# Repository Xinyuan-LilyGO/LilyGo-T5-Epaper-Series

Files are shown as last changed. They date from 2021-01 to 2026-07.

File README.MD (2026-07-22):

<div align="center" markdown="1">
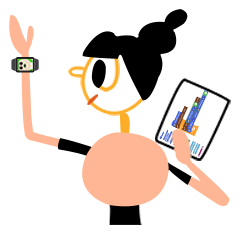
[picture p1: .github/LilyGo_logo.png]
LilyGo logo
  
</div>

<h1 align="center">LilyGo T5 2.13 E-Paper</h1>

### Product

| Product | SOC | Flash | PSRAM |
| --- | ----- | --- | ----- |
| [T5 2.13 Inch][1] | ESP32 | 4MB(Quad-SPI) | N.A |

[1]: https://lilygo.cc/products/t5-v2-3-1

<h2 align="left">Quick Start</h2>

### PlatformIO Quick Start

1. Install the **CH9102 USB bridge** driver for the first time.
   * [Windows](https://www.wch-ic.com/downloads/CH343SER_ZIP.html)
   * [Mac OS](https://www.wch-ic.com/downloads/CH34XSER_MAC_ZIP.html)
2. Install [Visual Studio Code](https://code.visualstudio.com/) and [Python](https://www.python.org/)
3. Search for the `PlatformIO` plugin in the `Visual Studio Code` extension and install it.
4. After the installation is complete, restart `Visual Studio Code`.
5. Select `File` -> `Open Folder` in the upper left corner, then select the `LilyGo-T5-Epaper-Series` directory.
6. Wait for the installation of third-party dependent libraries to complete.
7. Click on the `platformio.ini` file.
8. Uncomment one of the `src_dir = xxxx` lines so that only one is active. For example, to enable `src_dir = examples/Factory`, remove the leading `;` and save the file.
9. Click the (checkmark) symbol in the lower left corner to compile.
10. Connect the board to the computer via Micro-USB.
11. Click (arrow) to upload firmware.
12. Click (plug symbol) to monitor serial output.
13. If the upload fails or the USB device keeps flashing, please check the **FAQ** below.

### Arduino IDE Quick Start

1. Install the **CH9102 USB bridge** driver for the first time.
   * [Windows](https://www.wch-ic.com/downloads/CH343SER_ZIP.html)
   * [Mac OS](https://www.wch-ic.com/downloads/CH34XSER_MAC_ZIP.html)
2. Install [Arduino IDE](https://www.arduino.cc/en/software).
3. Install [Arduino ESP32](https://docs.espressif.com/projects/arduino-esp32/en/latest/).
4. Copy all folders in the `lib` directory to the `Sketchbook location` directory.
   How to find your library path, [see here](https://support.arduino.cc/hc/en-us/articles/4415103213714-Find-sketches-libraries-board-cores-and-other-files-on-your-computer).
   * Windows: `C:\Users\%USERNAME%\Documents\Arduino\libraries`
   * MacOS: `$HOME/Documents/Arduino/libraries`
   * Linux: `$HOME/Arduino/libraries`
5. Open the corresponding example:
   * Open the downloaded `LilyGo-T5-Epaper-Series`
   * Open `examples`
   * Select the sample file ending with `.ino`
6. In Arduino IDE, select the board and settings as shown below:

   | Name                                 | Value                                |
   | ------------------------------------ | ------------------------------------ |
   | Board                                | **ESP32 Dev Module**                 |
   | Port                                 | Your port                            |
   | CPU Frequency                        | 240MHz(WiFi/BT)                      |
   | Core Debug Level                     | None                                 |
   | Erase All Flash Before Sketch Upload | Disable                              |
   | Events Run On                        | Core1                                |
   | Flash Frequency                      | 80MHz                                |
   | Flash Mode                           | QIO                                  |
   | Flash Size                           | **4MB(32Mb)**                        |
   | JTAG Adapter                         | Disabled                             |
   | Arduino Runs On                      | Core1                                |
   | Partition Scheme                     | **Huge APP (3MB No OTA/1MB SPIFFS)** |
   | PSRAM                                | **Disable**                          |
   | Upload Speed                         | 921600                               |
   | Programmer                           | **Esptool**                          |

7. At the top of the sketch, select the screen model you are using: **DEPG0213BN** (default) or **GDEY0213B74**. Uncomment the corresponding line and comment out the other.

### Pins Map

| Name | GPIO NUM |
| --- | --- |
| Display power control | 12 |
| Display MISO | No Connect |
| Display MOSI | 23 |
| Display SCLK | 18 |
| Display DC | 17 |
| Display BUSY | 4 |
| Display RST | 16 |
| Display CS | 5 |
| SD SCK | 14 |
| SD MISO | 2 |
| SD MOSI | 15 |
| SD CS | 13 |
| Battery ADC Pin | 35 |
| Button BOOT | 0 |
| Button 1 | 39 |

* (Display power control) GPIO12 Only V2.4 Version , v2.3.1 version not have this pin

> [!IMPORTANT]
> The ESP32 uses IO2 as the SD card CS pin. You cannot upload software when the SD card is inserted, so remove the SD card before uploading.

### FAQ

- **What is the device's sleep current?**
   1. With the screen power completely off, the external wake-up rate of the ESP32 is approximately 30uA. A complete record of this can be found [here](./examples/DeepSleep/README.MD)

- **Can't upload any sketch? Please enter upload mode manually.**
  1. Connect the board via the USB cable.
  2. Press and hold the BOOT button.
  3. While holding BOOT, press the RST button.
  4. Release the RST button.
  5. Release the BOOT button.
  6. Upload the sketch.

### Resources

- [PCB Dimensions](./dimensions/T5_2.13.dxf)
- [PCB Step](./dimensions/LILYGO_T5%202.13.stp)
- [Schematic](./schematic/T5_2.13.pdf)
- [Cases from users](https://www.printables.com/search/models?ctx=models&q=TTGO+T5)

### Hardware Revision

#### V2.4

* Added GPIO12 control for screen power; improved deep-sleep power consumption (deep-sleep draw is approximately 30µA).
* Added a BOOT button to allow manual entry into download mode if the automatic download circuit fails.
* Optimized WiFi antenna for better WiFi performance.

#### V2.3.1

* Initial version

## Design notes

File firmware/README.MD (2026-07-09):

<div align="center" markdown="1">
  LilyGo logo
</div>

<h1 align = "center">🌟LilyGo-T5 2.13 Inch Firmware</h1>

## Use ESP Download Tool

* [Flash Download Tool User Guide](https://docs.espressif.com/projects/esp-test-tools/en/latest/esp32/production_stage/tools/flash_download_tool.html)

| Steps  | ESP32 Version |
| --- | --- |
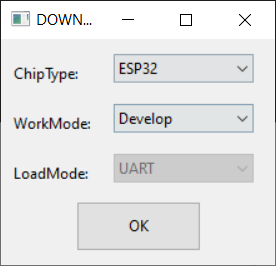
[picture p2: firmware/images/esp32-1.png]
| Step 1 |  |
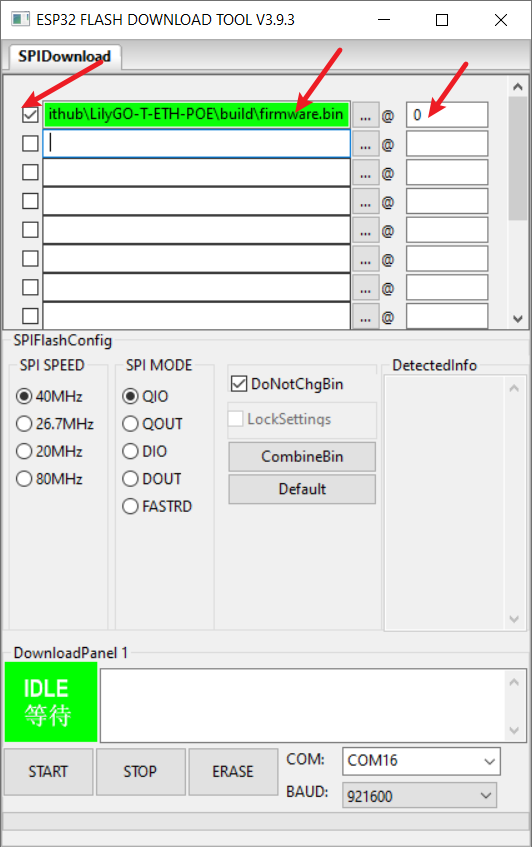
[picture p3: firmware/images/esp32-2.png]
| Step 2 |  |

### Use Web Flasher

* [ESP Web Flasher Online](https://espressif.github.io/esptool-js/)

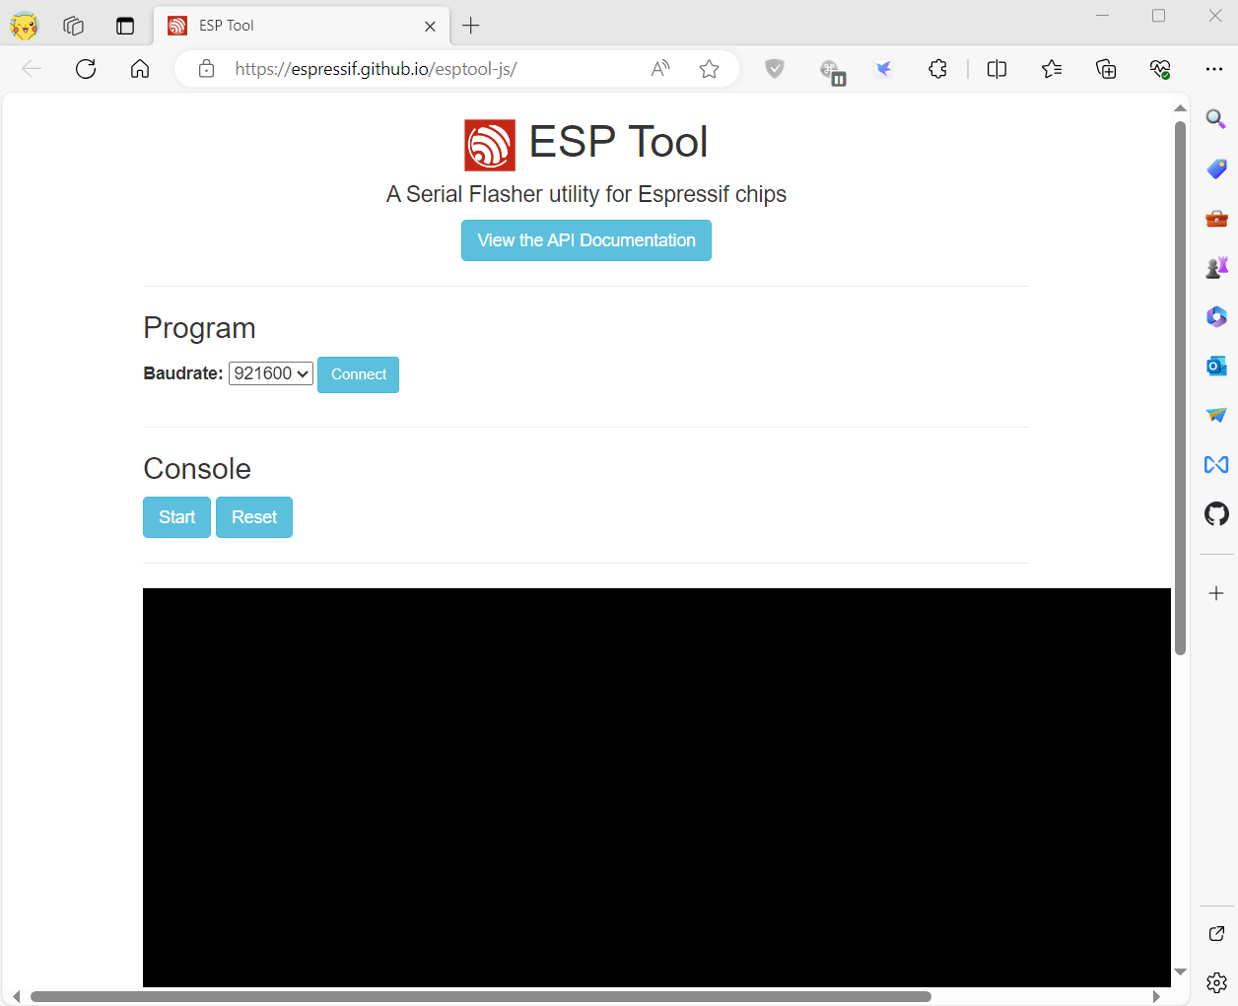
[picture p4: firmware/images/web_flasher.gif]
web_flasher


* Note that after writing is completed, you need to press RST to reset.

### Use command line

If system asks about install Developer Tools, do it.

```bash
python3 -m pip install --upgrade pip
python3 -m pip install esptool
```

In order to launch `esptool.py`, exec directly with this:

```bash
python3 -m esptool
```

<!-- For **ESP32-S3** use the following command to write

```bash
esptool --chip esp32s3  --baud 921600 --before default_reset --after hard_reset write_flash -z --flash_mode dio --flash_freq 80m 0x0 firmware.bin
``` -->

For **ESP32** use the following command to write

```bash
esptool --chip esp32  --baud 921600 --before default_reset --after hard_reset write_flash -z --flash_mode dio --flash_freq 80m 0x0 firmware.bin
```

# 2️⃣FAQ

- **Can't upload any sketch，Please enter the upload mode manually.**
   1. Connect the board via the USB cable
   2. Press and hold the BOOT button , While still pressing the BOOT button 
   3. Press RST button
   4. Release the RST button
   5. Release the BOOT button
   6. Upload sketch

> \[!IMPORTANT]
> ESP32 version Since the SD card uses IO2 as CS, you cannot upload software in the Arduino IDE when you insert the SD card, so you must remove the SD card when uploading new code
>

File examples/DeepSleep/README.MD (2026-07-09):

# Deepsleep Test

[LilyGo T5 V2.4 Deep Sleep Power Consumption Test Record](https://youtube.com/shorts/9wAvt5J69zs)

# GDEY0213B74 Aboud 30 uA

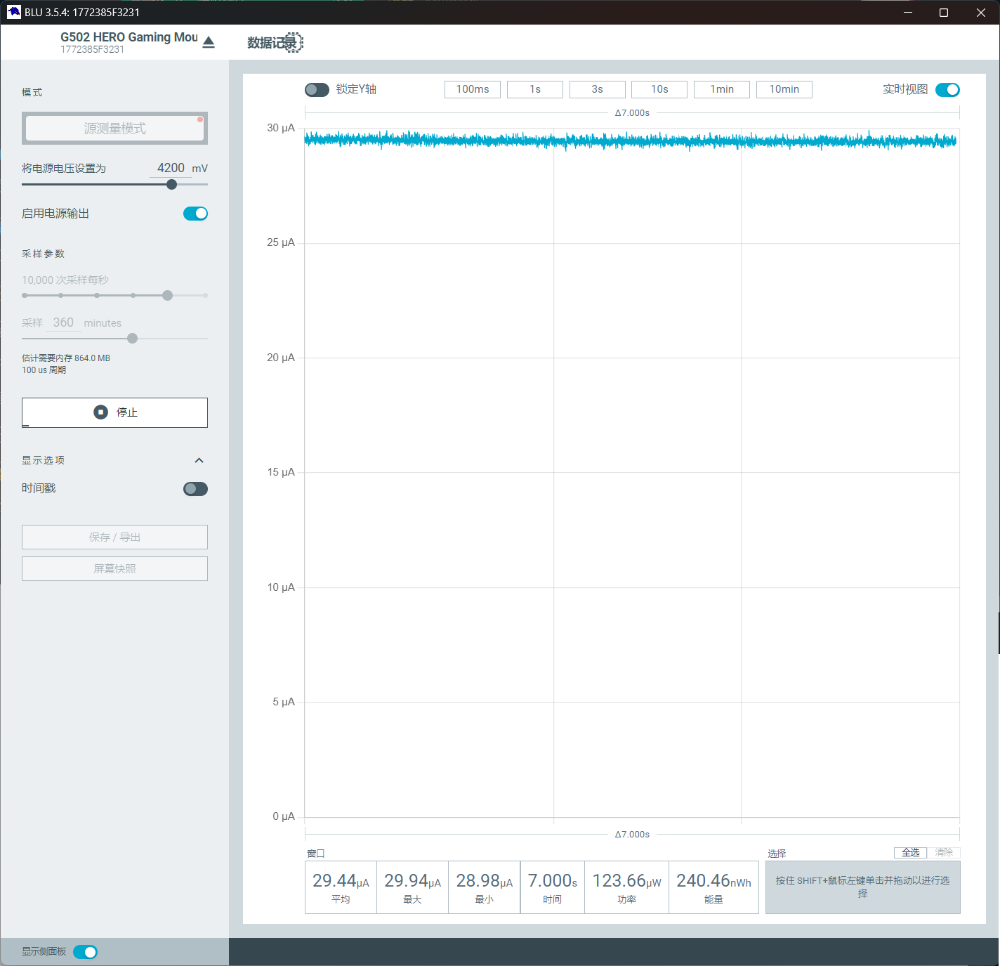
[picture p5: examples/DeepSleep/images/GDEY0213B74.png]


# DEPG0213BN Aboud 30 uA

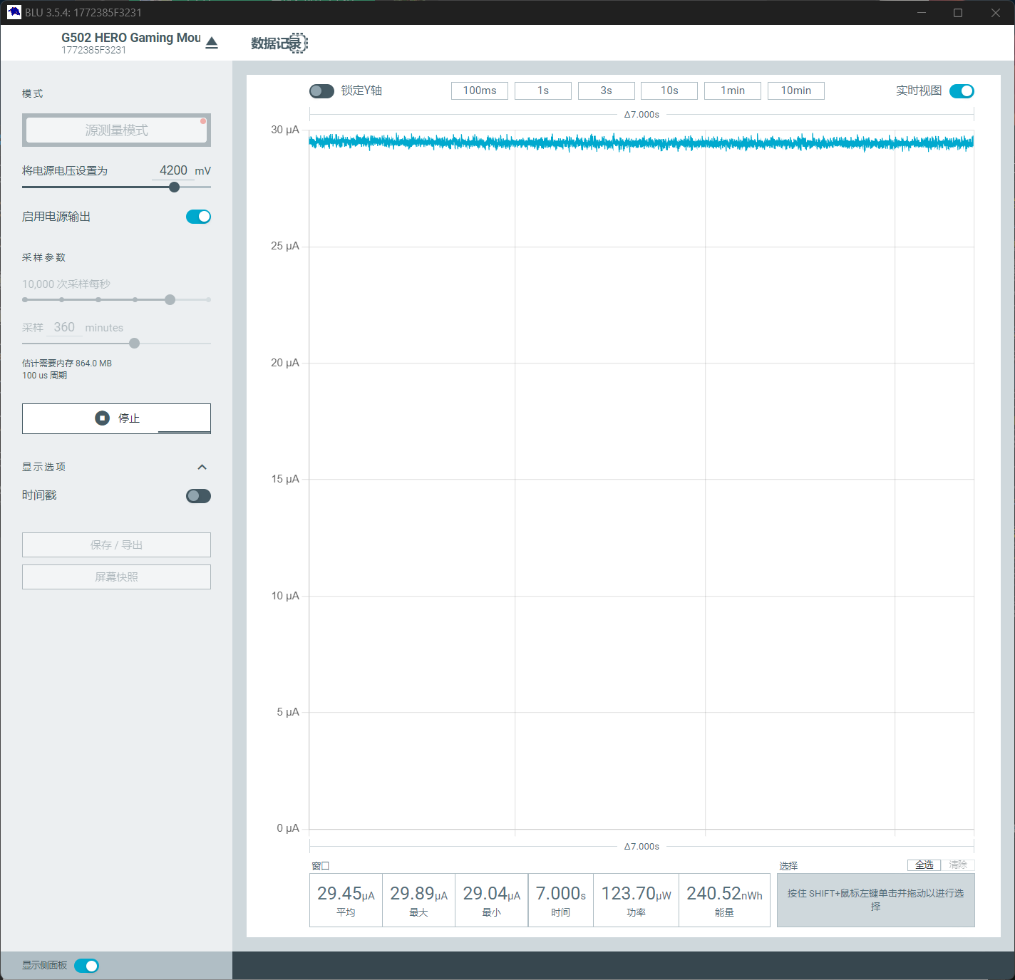
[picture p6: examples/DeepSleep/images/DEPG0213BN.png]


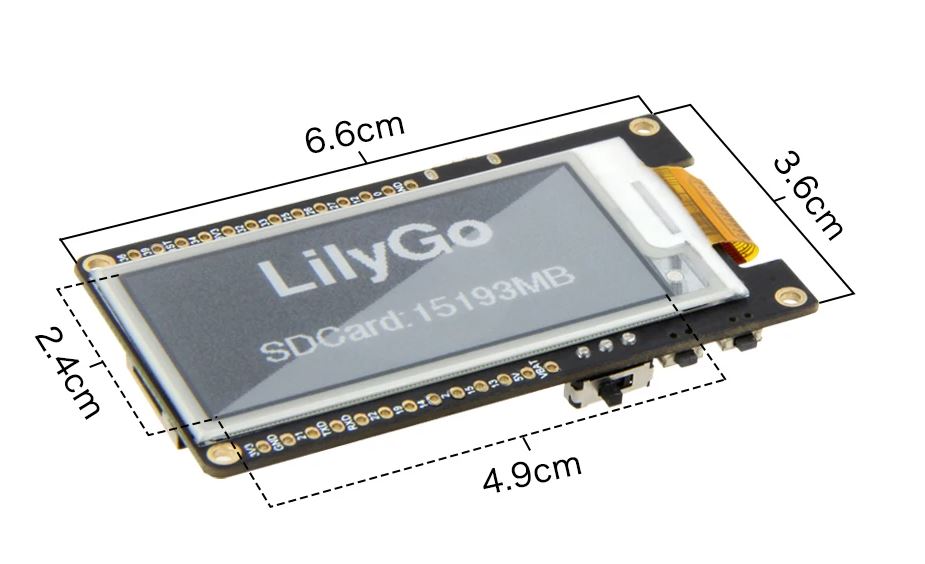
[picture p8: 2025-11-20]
dimensions/Dimensions1.JPG

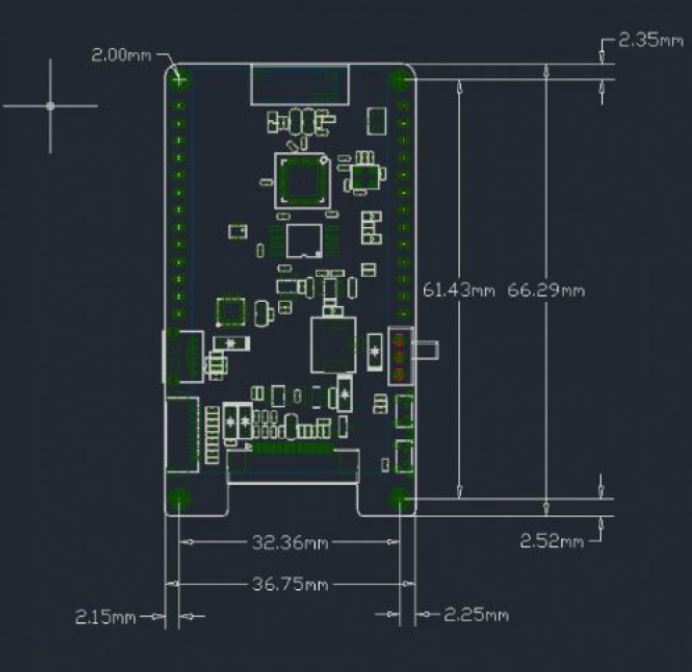
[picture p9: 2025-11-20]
dimensions/Dimensions.JPG

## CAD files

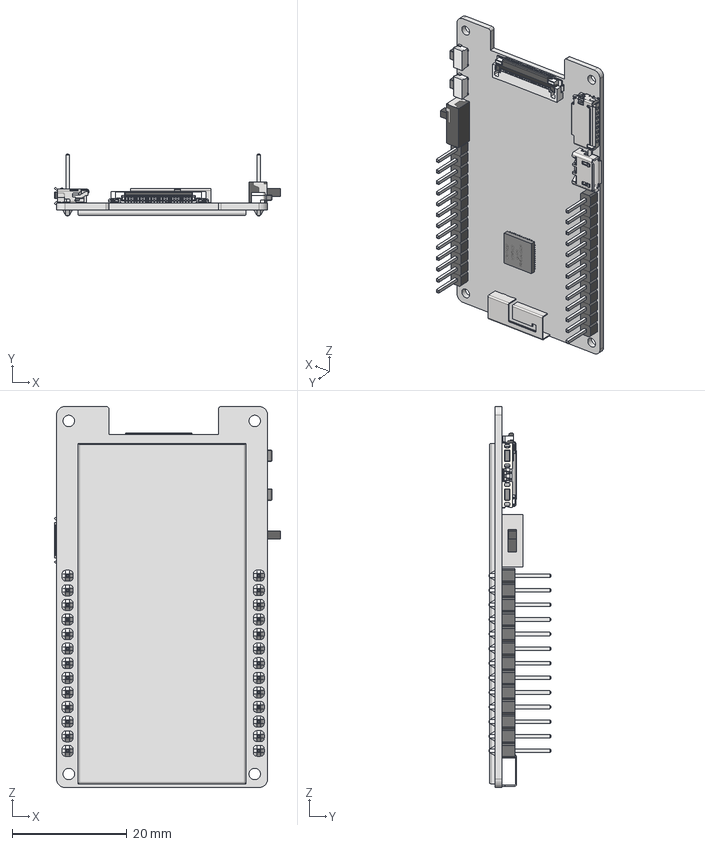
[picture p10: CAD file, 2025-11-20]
dimensions/LILYGO_T5 2.13.stp
39.4 x 10.8 x 66.3 mm
Плата
Antenna, ESP32-PICO-KIT
ESP32-PICO-D4, ESP32-PICO-KIT
Selector Switch
MicroSD Card Connector
Micro USB Shell
FFC Pitch 24
Tact Switch 2x4x3.5MM x 2
Дисплей
2.54 4W Header x 2
2.54 4W Header_ x 10

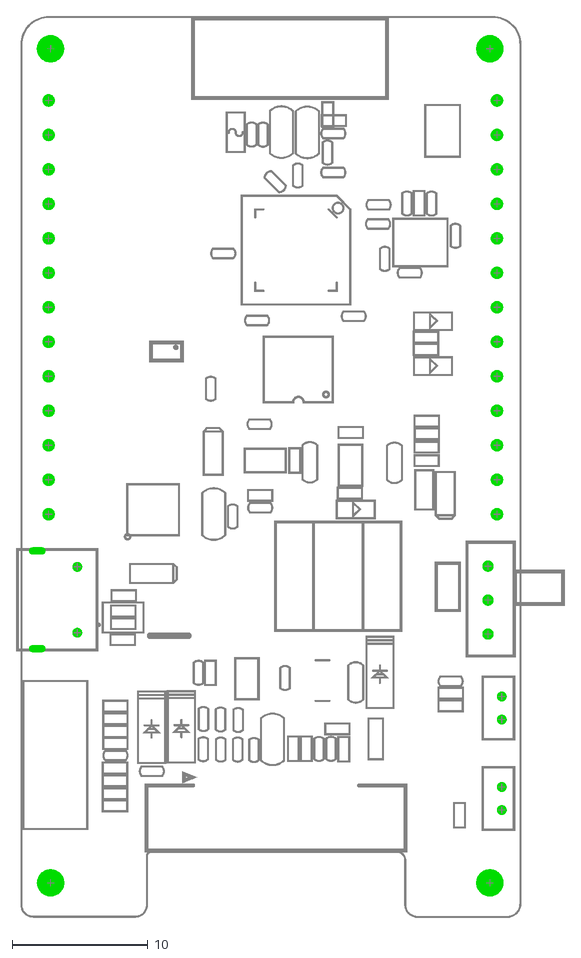
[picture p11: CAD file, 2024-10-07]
dimensions/T5_2.13.dxf
40.4 x 66.4

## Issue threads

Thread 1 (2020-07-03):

Support for GxEPD2?

holgerlembke, 2020-07-03:
Hi.

Is there any support for GxEPD2?

RalfJL, 2021-01-05:
Hi,

for the V2.2 it might be coming up.
See
https://forum.arduino.cc/index.php?topic=487007.msg4845514#msg4845514

lewisxhe, 2021-01-21:
Support, as long as there is a driver in GxEPD2, it can be used. My warehouse is just a demonstration for some novices.

holgerlembke, 2021-01-21:
I appreciate your great product support for some novices.

Closed 2021-01-21.

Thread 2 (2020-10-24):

T5 v2.3 rev. 2.13

ejs-ejs, 2020-10-24:
Hi,
Thank you for the code.
I was playing with GxEPD library and could not get the display.
The T5 version 2.3 rev 2.13 uses GxGDEH0213B73 instead of GxGDEH0213B72. Pins seem to be the same. Maybe the includes could be selected bys #define too?

Also, I've removed #define prom the start of the H file and I can use it as a library:
`#define TTGO_T5_2_3 1
#include <TTGO_T5_boards.h>`

The mentioned code in the H file is as follows:
`#elif (TTGO_T5_2_0) || (TTGO_T5_2_3)
  // #include <GxGDE0213B1/GxGDE0213B1.h>      // 2.13" b/w
  // #include <GxGDE0213B72/GxGDE0213B72.h>      // 2.13" b/w     GxGDE0213B1 升级版本
  //#include <GxGDEH0213B72/GxGDEH0213B72.h> // 2.13" b/w           GxGDE0213B72 升级版本 默认LilyGO的出厂屏幕都是这种
 #include <GxGDEH0213B73/GxGDEH0213B73.h> // 2.13"

  #define SPI_MOSI 23
  #define SPI_MISO -1
  #define SPI_CLK 18

  #define ELINK_SS 5
  #define ELINK_BUSY 4
  #define ELINK_RESET 16
  #define ELINK_DC 17

  #define SDCARD_SS 13
  #define SDCARD_CLK 14
  #define SDCARD_MOSI 15
  #define SDCARD_MISO 2

  #define BUTTON_3 39
  #define BUTTONS_MAP \
    {               \
        39          \
    }

  #define SPEAKER_OUT -1

  #ifdef _GxGDEH0213B72_H_
    #define EPD_WIDTH GxGDEH0213B72_WIDTH
    #define EPD_HEIGHT GxGDEH0213B72_HEIGHT
    #define EPD_VISIBLE_WIDTH GxGDEH0213B72_VISIBLE_WIDTH
  #endif

  #ifdef _GxGDEH0213B73_H_
    #define EPD_WIDTH GxGDEH0213B73_WIDTH
    #define EPD_HEIGHT GxGDEH0213B73_HEIGHT
    #define EPD_VISIBLE_WIDTH GxGDEH0213B73_VISIBLE_WIDTH
  #endif`

ejs-ejs, 2020-10-24:
Sorry, wrong repo...

Closed 2020-10-24.

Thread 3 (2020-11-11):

T5 v2.3 2.13 Board Turn off LED

misaalanshori, 2020-11-11:
I have this board and would like to have it very low power. Is it possible to disable the Blue LED or will I need to just desolder it? It would be great if there is another way to disable it as I don't trust my skill in soldering and I don't know if that led is important (probably not, but I'm not sure).

romoloman, 2020-12-14:
The led should be desoldered, there is no way to disable it (have a lok to the schematics), but for running really low power there are other mods that should be made:
1) A pullup resistor is required between 3.3V and the CS pin on the flash (without that the flash will be always on draining 3 mA
2) The two LDO on board have a quiescent current of about 40uA each, replace them with RT9080 33GJA (2 uA each and the chips are pin to pin compatible)
3) The CP2104 is also draining 200 uA even if not used you need to cut the power supply line to the chip

After these mods I was able to achive less then 30uA in deep sleep mode.

if 318uA is sufficient for you just desolder the led and put a 100K resistor between pin 1 ad 8 of the flash.

I hope Xinyuan makes this mods on the board, maybe making a new version of the board

clonesht, 2021-01-04:
There is a non-hw way to reduce flash memory power usage:

> pinMode(13, OUTPUT);
> digitalWrite(13, HIGH);
> gpio_deep_sleep_hold_en();

[source: reddit](https://old.reddit.com/r/esp32/comments/idinjr/36ma_deep_sleep_in_an_eink_ttgo_t5_v23/ghx00sa/)

@romoloman do you have any stability issues with the RT9080-33GJ5 LDO mod?

According to a [comment](https://web.archive.org/web/20201112030913/https://blog.voneicken.com/2018/lp-wifi-esp32-boards/) it may drop out on peaks:

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

As alternative I have not tried, but [there is some positive experiences](https://www.esp32.com/viewtopic.php?t=6667) on [SOT23-5 version of Holtek HT7833](https://www.holtek.com.tw/documents/10179/82844a36-1633-498c-a6e3-4d99f2d0f6d7) and looks like it have the same pin assignment. (4mA LQC / 500mA out)

lewisxhe, 2021-01-21:
The blue one is the charging indicator, you can remove it without needing to.

Closed 2021-01-21.

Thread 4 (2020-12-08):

Sample code for V2.4

earcam, 2020-12-08:
Hello,

There's currently no sample code for LilyGo T5 V2.4.  Would you please add an example for this board?

Thanks

lewisxhe, 2021-01-21:
In the original address, it has now been updated, V2.4 pin mapping is the same as GxEPD, you can directly use the GxEPD example.

Closed 2021-01-21.

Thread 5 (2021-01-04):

LiPo Voltage Measurement v2.3

Anton2k, 2021-01-04:
Hi, having a hard time trying to figure out how to measure the voltage of the LiPo battery, anyone had success?

Thanks,

Anton2k, 2021-01-04:
Update, I have now found that there is a Pin 35 BAT_TEST, that I can use to measure voltage, the issues is the reading is 2000+ when I was expecting it to me 3.9v I suspect the reading is in MV or something and I need to run it through some calculation?

RalfJL, 2021-01-05:
Have a look at the schematics.
There are 2 100kOhm resistors to prevent the input voltage from being higher than 3.3 V.
So you have to multiply the reading by 2 to get the correct measurement.

By the way, there are plenty of complains on the internet that the ADC is not very good on a ESP32.
Google it and you will find some code to smooth it a little bit.
And don't take the measurement when BLE or WiFi is on. Readings become worse.

Anton2k, 2021-01-07:
Just encase anyone is looking, here us my solution...

`  esp_adc_cal_characteristics_t adc_chars;
  esp_adc_cal_value_t val_type = esp_adc_cal_characterize((adc_unit_t)ADC_UNIT_1, (adc_atten_t)ADC_ATTEN_DB_2_5, (adc_bits_width_t)ADC_WIDTH_BIT_12, 1100, &adc_chars);
  float measurement = (float) analogRead(35);
  float battery_voltage = (measurement / 4095.0) * 7.05;
`

RalfJL, 2021-01-09:
I would recommend the following video
https://www.youtube.com/watch?v=UAJMLTzrM9Q
Normally I am happy with an average of 10 measurements and some correction I found on the internet
So my solution is more that:
double rawVoltage() {
  // read analog and make it more linear
  double reading = analogRead(VOLT_PIN);
  for (int i = 0; i < 10; i++) {
    reading = (analogRead(VOLT_PIN) + reading * 9) / 10;
  }
  if (reading < 1 || reading > 4095) return 0;
  return -0.000000000000016 * pow(reading, 4) + 0.000000000118171 * pow(reading, 3) - 0.000000301211691 * pow(reading, 2) + 0.001109019271794 * reading + 0.034143524634089;
}

All that without wifi or BLE

Closed 2021-01-07.

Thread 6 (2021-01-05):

T5 V2.2 2.9" schematics is wrong

RalfJL, 2021-01-05:
Hi,
the schematics for the above boards seams to be wrong.
The red LED is on with
digitalWrite(26, LOW);
So I assume it has the same connection as all the other boards:
+ -> Resistor -> LED -> PIN26

lewisxhe, 2021-01-21:
The green one is the power indicator, and the red one can be controlled by GPIO26. The green light can be removed if it is not needed.

L-oled, 2022-04-24:
Hi @RalfJL , I was facing to similar issue on the same board when trying to debug with openOCD (issue to find JTAG pinout):
it seem that there is "differents" v2.2 revision of this board.... My board have a JP1 20 pin connectors pinout that corresponds to the one here: http://www.lilygo.cn/prod_view.aspx?TypeId=50061&Id=1397&FId=t3:50061:3
But I didn't manage to find schematics, including on this directory (v2.2 don't match). Except for JP1 pinout, my board looks like a v1.2

Closed 2021-01-21.

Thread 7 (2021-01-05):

T5 V2.2 2.9" green LED can't be turned off

RalfJL, 2021-01-05:
Hi,
according to the schematics the green LED is hardwired and always on.

This is not very good, if you want to run the board on a battery.
There is a battery connector so I assume it was intended for low power consumption.
There should be a better way to disable the green LED, than cutting the resistor off the board.

Regards

lewisxhe, 2021-01-21:
It is a power indicator and cannot be controlled by software, if you don't need to remove it.

Closed 2021-01-21.

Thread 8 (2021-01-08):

Under voltage & Overcharge Protection

Anton2k, 2021-01-08:
Hi, does the T5 v2.3 have built in cut off protection when using Lipo / Ion cells? and does it also have over charge protection? If so can you let me know what values these are, both cut off and over charge. I don't want to blow cells up or discharge them to the point they die.

Thanks,

Anton2k, 2021-01-10:
?

lewisxhe, 2021-01-21:
LILYGO T5 2.3 uses the TP4056 charging chip, which has charging protection, but it does not have reverse connection protection. When you use it, be careful not to mistake the power polarity.

Anton2k, 2021-01-21:
@lewisxhe thanks, but does it have cut off protecting, I need to know at what voltage does discharging stop at, 2.5v 3v?

Anton2k, 2021-01-29:
@lewisxhe ?

lewisxhe, 2021-01-29:
Battery over-discharge protection voltage: 2.5V  @Anton2k

haldi4803, 2021-02-08:
So you guys can confirm that battery works for you?
Because on my T5 v2.2 20181116 does not work when powering via Batteryconnector. I've plugged a battery, i've connected a 4v PSU but the T5 wouldn't even boot up :( No Green light, no Programm start. Do i have faulty hardware?

Closed 2021-01-21.

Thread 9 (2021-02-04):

T5 V2.2 Partial Update Example not working

haldi4803, 2021-02-04:
Hi,
I got the TTGO T5 V2.2 with revision 20181116 using #include <GxGDEH029A1/GxGDEH029A1.h>      // 2.9" b/w the GxEPD_Example works fine.
But the GxEPD_Partial_Update_Example with the same settings seems to work only in Serial but doesn't show anything on the Screen. Not even refreshing. Screen is simply dead.

I think this might be an issue with:
`display.updateWindow(0, 0, GxEPD_WIDTH, GxEPD_HEIGHT, false);`

Because when i use Serial.println before it works but afterwards it doesn't...

haldi4803, 2021-02-04:
Oh -.- the     SPI.begin(EPD_SCLK, EPD_MISO, EPD_MOSI); is missing in the Setup!

Closed 2021-02-04.

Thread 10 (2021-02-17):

T5 4.7 Inch Display

RobertSmart, 2021-02-17:
Hi,

Does this support the lilygo T5 4.7 screen?

Where can I find the firmware for this screen?

lewisxhe, 2021-02-22:
It's here  ， https://github.com/Xinyuan-LilyGO/LilyGo-EPD47

Closed 2021-02-22.

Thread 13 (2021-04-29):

T5 V2.2 2.9" consuming too much power

RalfJL, 2021-04-29:
Hi,
I removed the resistor in front of the green led,
 putting display driver to deep sleep,
putting esp32 to deep sleep
but still the board is consuming 9,35 mA.
This is unacceptable if you want to run it on a battery.
So what is left:
- the UART chip is there any way to turn it off
- the SD-card chip can I put that into deep sleep
- the battery charging chip is there any need to put it in power save mode

Is there any way to reduce the power consumption even more?

joysfera, 2021-05-16:
Seems like the CP2104 itself consumes at least 7 mA. I've read that adding a pulldown to its D- helps a lot.

joysfera, 2021-05-16:
It's possible to lower the consumption in sleep by about 2 mA by disabling flash:
```
pinMode(16, OUTPUT);
digitalWrite(16, HIGH);
gpio_deep_sleep_hold_en();
```
Still 8 mA left.

RalfJL, 2021-05-17:
Hi joysfera,
this is a great hack. Unfortunately everything is so tiny that I can't solder a pulldown resistor to anything.
So unless TTGO changes the layout, I can't see how this board can be powered from battery.
This is a real shame because I put quite some effort to move away from TCP/IP and WiFi to ESP NOW which is much more power saving.
All in vain because of the board itself.

So let's hope that TTGO is learning from this.

Thanks for sharing this information

Ralf

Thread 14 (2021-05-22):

Cannot upload sketch to T5 v2.13

arcaartem, 2021-05-22:
Hello,

I've followed the instructions on this repo and got up to the point where the board and the library is installed. Whenever I try to upload the sketch, I'm getting an error `A fatal error occurred: Failed to connect to ESP32: Timed out waiting for packet header`

I'm on Windows. When I connect the device through USB, I see a new COM port in the device manager. If I open serial monitor on Arduino IDE, I can see the board communicates information on 115200 baud. But the default values for the board when uploading is different. Even if I set them the same, the issue is still there. Is there any other step that we need to do in order to upload sketches to the device?

Thanks!

arcaartem, 2021-05-27:
The method in [this issue](https://github.com/Xinyuan-LilyGO/LilyGo-T-Call-SIM800/issues/89) works for this version of the board as well:

* Short IO0 to GND
* Press the reset button
* Upload the sketch

Closed 2021-05-30.

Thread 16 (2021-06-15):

MacBook Intel CPU with MacOS 11.4 (Big Sur) can not upload anything to T5 board

solocatz, 2021-06-15:
For me only affect Lilygo product, my other low cost esp32 clones are fine.

Try to upload GetChipID sample:

esptool.py v3.0-dev
Serial port /dev/cu.usbmodem526F0051341
Connecting........__
Chip is ESP32-D0WDQ6-V3 (revision 3)
Features: WiFi, BT, Dual Core, 240MHz, VRef calibration in efuse, Coding Scheme None
Crystal is 40MHz
MAC: 08:3a:f2:47:3b:2c
Uploading stub...

A fatal error occurred: Failed to write to target RAM (result was 01070000)
A fatal error occurred: Failed to write to target RAM (result was 01070000)

Here is a link of discussion.
[ESPTool does not work on TTGO product](https://github.com/espressif/esptool/issues/280#issuecomment-861084553)

don41382, 2021-06-15:
I have the same issue with my Macbook M1 Air on Big Sur 11.4.

Please fix!

wecodemx, 2021-06-30:
Same issue here on Macbook intel on Big Sur 11.4
Module: LILYGO® TTGO T-Call V1.4 / V1.5 ESP32

don41382, 2021-06-30:
Good news. After updating with new driver CP102 v6.0.1 from Silabs - it's finally working on my M1.

[Silabs Page](https://www.silabs.com/developers/usb-to-uart-bridge-vcp-drivers)

Let me know, if this works for you.

elajf, 2021-07-01:
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

This didn't work for me but I think mine has a different UART chip, a CH1902. Seems that could be the problem.

matteocarnelos, 2021-07-15:
Same problem here

losdevnull, 2021-07-19:
Same problem here.  Any workaround directly on Mac instead of trying to do this in Windows/linux VMs?

Closed 2022-06-01.

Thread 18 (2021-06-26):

Support in EspEasy firmware

jbaream, 2021-06-26:
Hi,

It would be nice to have a plugin to control these nice eink screens from the firmware ESPEasy. Currently only Lolin ePaper screens are supported. I attach the source file of the plugin for these screens. Is it too difficult to code something similar? What do you think? I am not a expert in advanced programming as to do it. Maybe this can be accomplished by modifying the attached source file.

Best regards,

Jose.
[_P096_eInk.ino.zip](https://github.com/Xinyuan-LilyGO/LilyGo-T5-Epaper-Series/files/6719504/_P096_eInk.ino.zip)

lewisxhe, 2022-06-01:
Looks good, I can try it. Thanks for your advice

Closed 2022-06-01.

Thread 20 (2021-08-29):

lewisxhe / GxEPD boards.h is missing definition for T-Display E-Paper

ShotokuTech, 2021-08-29:
In  lewisxhe / GxEPD boards.h, line 213 change:
#elif defined(LILYGO_EPD_DISPLAY)
to:
#elif defined(LILYGO_EPD_DISPLAY_102)
And this resolves the problem.

LilyGO, 2021-09-11:
Please create a new board. h file, copy the following content into it

#pragma once

#if defined(LILYGO_T5_V213)

#define EPD_MOSI                (23)
#define EPD_MISO                (-1)
#define EPD_SCLK                (18)
#define EPD_CS                  (5)

#define EPD_BUSY                (4)
#define EPD_RSET                (16)
#define EPD_DC                  (17)

#define SDCARD_CS               (13)
#define SDCARD_MOSI             (15)
#define SDCARD_MISO             (2)
#define SDCARD_SCLK             (14)

#define BUTTON_1                (39)
#define BUTTONS                 {39}

#define BUTTON_COUNT            (1)

#define LED_PIN                 (19)
#define LED_ON                  (LOW)

#define ADC_PIN                 (35)

#define _HAS_ADC_DETECTED_
#define _HAS_LED_
#define _HAS_SDCARD_

#elif defined(LILYGO_T5_V22)

#define EPD_MOSI                (23)
#define EPD_MISO                (2)
#define EPD_SCLK                (18)
#define EPD_CS                  (5)

#define EPD_BUSY                (4)
#define EPD_RSET                (12)
#define EPD_DC                  (19)

#define SDCARD_CS               (13)

#define BUTTON_1                (37)
#define BUTTON_2                (38)
#define BUTTON_3                (39)

#define BUTTONS                 {37,38,39}
#define BUTTON_COUNT            (3)

#define LED_PIN                 (26)
#define LED_ON                  (HIGH)

#define ADC_PIN                 (35)

#define SPERKER_PIN             (25)

#define LEDC_CHANNEL_0          (0)
#define _HAS_ADC_DETECTED_
#define _HAS_LED_
#define _HAS_SPEAKER_
#define _BUILTIN_DAC_
#define _USE_SHARED_SPI_BUS_
#define _HAS_SDCARD_

#elif defined(LILYGO_T5_V24)

#define EPD_MOSI                (23)
#define EPD_MISO                (-1) //elink no use
#define EPD_SCLK                (18)

#define EPD_BUSY                (4)
#define EPD_RSET                (16)
#define EPD_DC                  (17)
#define EPD_CS                  (5)

#define SDCARD_CS               (13)
#define SDCARD_MOSI             (15)
#define SDCARD_MISO             (2)
#define SDCARD_SCLK             (14)

#define BUTTON_1                (37)
#define BUTTON_2                (38)
#define BUTTON_3                (39)

#define SPK_POWER_EN                (19)

#define BUTTONS                 {37,38,39}
#define BUTTON_COUNT            (3)

#define LED_PIN                 (26)
#define LED_ON                  (LOW)

#define ADC_PIN                 (35)

#define SPERKER_PIN             (25)

#define LEDC_CHANNEL_0          (0)
#define _HAS_ADC_DETECTED_
#define _HAS_LED_
#define _HAS_SPEAKER_
#define _BUILTIN_DAC_
#define _HAS_SDCARD_
#define _HAS_PWR_CTRL_
#elif defined(LILYGO_T5_V28)

#define EPD_MOSI                (23)
#define EPD_MISO                (-1)
#define EPD_SCLK                (18)
#define EPD_CS                  (5)

#define EPD_BUSY                (4)
#define EPD_RSET                (16)
#define EPD_DC                  (17)

#define SDCARD_CS               (13)
#define SDCARD_MOSI             (15)
#define SDCARD_MISO             (2)
#define SDCARD_SCLK             (14)

#define BUTTON_1                (37)
#define BUTTON_2                (38)
#define BUTTON_3                (39)

#define IIS_WS                  (25)
#define IIS_BCK                 (26)
#define IIS_DOUT                (19)

#define ICS43434_WS             (33)
#define ICS43434_BCK            (32)
#define ICS43434_DIN            (27)

#define I2C_SDA                 (21)
#define I2C_SCL                 (22)

#define BUTTONS                 {37,38,39}
#define BUTTON_COUNT            (3)

#define LED_PIN                 (22)
#define LED_ON                  (HIGH)

#define ADC_PIN                 (35)

#define _HAS_ADC_DETECTED_
#define _HAS_LED_
// #define _HAS_SPEAKER_
#define _HAS_SDCARD_

#elif defined(LILYGO_T5_V102)

#define EPD_MOSI                (21)
#define EPD_MISO                (-1)
#define EPD_SCLK                (22)
#define EPD_CS                  (5)

#define EPD_BUSY                (34)
#define EPD_RSET                (4)
#define EPD_DC                  (19)

#define SDCARD_CS               (13)
#define SDCARD_MOSI             (15)
#define SDCARD_MISO             (2)
#define SDCARD_SCLK             (14)

#define BUTTON_1                (36)
#define BUTTON_2                (39)
#define BUTTON_3                 (0u)//BUTTON_3
#define BUTTONS                 {36,39,0}
#define BUTTON_COUNT            (3)

#define POWER_ENABLE			(27)

#define ADC_PIN                 (35)

#define _HAS_ADC_DETECTED_
#define _HAS_SDCARD_

#elif defined(LILYGO_T5_V266)

#define EPD_MOSI                (23)
#define EPD_MISO                (-1)
#define EPD_SCLK                (18)
#define EPD_CS                  (5)

#define EPD_BUSY                (34)
#define EPD_RSET                (4)
#define EPD_DC                  (19)

#define SDCARD_CS               (13)
#define SDCARD_MOSI             (15)
#define SDCARD_MISO             (2)
#define SDCARD_SCLK             (14)

#define BUTTON_1                (39)
#define BUTTONS                 {39}

#define BUTTON_COUNT            (1)

#define LED_PIN                 (12)
#define LED_ON                  (LOW)

#define ADC_PIN                 (35)

#define _HAS_ADC_DETECTED_
#define _HAS_LED_
#define _HAS_SDCARD_

#elif defined(LILYGO_EPD_DISPLAY_102)

#define EPD_MOSI                (21)
#define EPD_MISO                (-1)
#define EPD_SCLK                (22)
#define EPD_CS                  (5)

#define EPD_BUSY                (18)
#define EPD_RSET                (23)
#define EPD_DC                  (19)

#define EPD_POWER_ENABLE        (14)

#define BUTTON_1                (35)
#define BUTTON_COUNT            (1)

#define ADC_PIN                 (35)
#define RGB_STRIP_PIN           (4)
#define RGB_STRIP_COUNT         (1)

#define _HAS_ADC_DETECTED_
#define _HAS_POWER_CONTROL_
#define _HAS_RGB_PIXEL_

#elif defined(LILYGO_EPD_DISPLAY_154)

#define EPD_MOSI                (13)
#define EPD_MISO                (-1)
#define EPD_SCLK                (14)
#define EPD_CS                  (15)

#define EPD_BUSY                (16)
#define EPD_RSET                (17)
#define EPD_DC                  (2)
#define EPD_BACKLIGHT_PIN       (0)

#define EPD_POWER_ENABLE        (5)

#define BUTTON_1                (35)
#define BUTTON_COUNT            (1)

#define ADC_PIN                 (34)
#define MOTOR_PIN               (4)

#define GPS_TX_PIN              (22)
#define GPS_RX_PIN              (21)
#define GPS_1PPS_PIN            (19)
#define GPS_RESET_PIN           (23)
#define GPS_WAKEUP_PIN          (18)

#define _HAS_ADC_DETECTED_
#define _HAS_POWER_CONTROL_
#define _HAS_GPS_

#else
#error "Please select model !!!"
#endif

carl3, 2022-02-09:
The examples inconsistently use LILYGO_EPD_DISPLAY and LILYGO_EPD_DISPLAY_102 . The "T-Display E-Paper 1.02inch" https://www.aliexpress.com/item/1005002536380666.html with a neopixel RGB LED uses LILYGO_EPD_DISPLAY.

Some of the examples use LILYGO_EPD_DISPLAY_102 instead of LILYGO_EPD_DISPLAY (e.g. hello_world) and some use both (incorrectly, as in GxEPD_Example.ino). In the lewisxhe repo the  Apr 14, 2021  update changed LILYGO_EPD_DISPLAY to LILYGO_EPD_DISPLAY_102 in some examples, but was not added to boards.h. You can define both LILYGO_EPD_DISPLAY_102 and LILYGO_EPD_DISPLAY, but some examples will cause problems.

Probably the boards.h should use ` #elif defined(LILYGO_EPD_DISPLAY) || defined(LILYGO_EPD_DISPLAY_102)` but most examples seem to use LILYGO_EPD_DISPLAY.

lewisxhe, 2022-08-08:
If there is still a problem, please reopen the issue

Closed 2022-08-08.

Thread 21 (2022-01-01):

Battery Voltage example

Martenz, 2022-01-01:
I’m trying to understand how to read battery voltage 1s plugged to the onboard connector but can’t find some good documentation or examples specific for this board.. do I need to create a voltage divider .. is it included in the board?

I have a 1.54 bw and a 2.13 bwr models with speaker.

I tried several how to but none of them works..
please help!

Thanks,

Martino

lewisxhe, 2022-06-01:
All boards have resistor dividers, which one do you use?

lewisxhe, 2022-08-08:
If there is still a problem, please reopen the issue

Closed 2022-08-08.

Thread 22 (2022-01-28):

Unable to use I2C

ChristopheLaurent, 2022-01-28:
I got the T5-2.13 and I try to connect a SCD41 CO2 sensor using I2C. This is basically the same thing as in this tutorial: https://github.com/Sensirion/arduino-ble-gadget/blob/master/documents/SCD4x_BLE_Gadget_Tutorial.md .

The classic scan of I2C bus shows that my sensor is there at address 0x67. So far so good. But when the T5-2.13 is sending commands to the sensor, I get error message "Error trying to execute readMeasurement(): Received NACK on transmit of address". I get this error without any code related to SPI or Ink screen. If I plug a regular ESP32 dev kit instead of the the T5-2.13 , then run the same code on the regular ESP32 dev kit, it works very well, without any I2C error.
I did not put any pull up resistor in both cases, because there is already one on the sensor breakout. In both cases I powered the T5-2.13 and the ESP32 dev kit with USB from my computer.

The peak current @ 3.3V for the SCD41 is 205 mA. Is this issue related to the 3V3 LDO on the T5-2.13 that could be too weak ? Looking at the diagram of the T5-2.13 ( https://github.com/re-innovation/TTGO_EPaper/blob/master/TTGO_Datasheets/T5_V2.3.pdf ) I noticed 2 LDOs, one for 3V3 and one for VCC_IO, but I can only see 3V3 on the pinout.
Any suggestion ?

[EDIT 1] I just tried using another (simpler) sensor: INA 219 DC Current monitor. It works well with regular ESP32 dev kit, not with the T5-2.13: It fails calling ina219.begin(). I then tried using 2 other pins for I2C: pin 25 & pin 26. Still the same problem, it works on ESP32 dev kit but fails the same way on the T5-2.13.

Did someone already manage to use I2C on T5-2.13 ? Could you please provide an example of T5-2.13 displaying ambiant temperature from an I2C sensor, or something along these lines ?

[Edit 2] I eventually found the cause of my problem: solder ! Please close this issue...

Closed 2022-02-23.

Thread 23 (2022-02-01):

The T-Display 1.02 E-Paper schematic is missing

carl3, 2022-02-01:
Can you upload the T-Display E-paper 1.02 schematic? (Aliexpress item 1005002536380666) It would be useful to examine power consumption, input voltage limits, and charging based on the board parts. (The product page links to this github repo.) Perhaps this is the EPD display, but the product on this is also not linked in the README.md

carl3, 2022-06-22:
It looks like the schematic added is the T92 with a 2.66 inch display, seems the same as the T5wth 2.66. The schematic for the T-Display E-paper 1.02 schematic is still missing and not linked. Thanks for updating the readme with a link to the T-Display product.

lewisxhe, 2022-08-08:
The schematic has been added, if there is still a problem, please reopen the issue

Closed 2022-08-08.

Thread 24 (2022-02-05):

Compiling error on LilyGo 2.13 ePaper display (DEPG0213BN)

levycarneiro, 2022-02-05:
Hello!

I'm trying to use a LilyGo 2.13 ePaper display. The model is DEPG0213BN.

I followed the steps in the github repository: Xinyuan-LilyGO/LilyGo-T5-Epaper-Series.

1. I installed Adafruit-GFX library, and the GxEPD library from this repository: https://github.com/lewisxhe/GxEPD

2. I copied all the files from https://github.com/lewisxhe/GxEPD/tree/master/src to my libraries folder.

3. I took the example code from the github repository at  Xinyuan-LilyGO/LilyGo-T5-Epaper-Series/blob/master/examples/GxEPD_Example/GxEPD_Example.ino

4. I uncommented the following lines:

```
#define LILYGO_T5_V213
```

and

```
#include <GxDEPG0213BN/GxDEPG0213BN.h>    // 2.13" b/w  form DKE GROUP
```

5. In my Arduino IDE, I have "ESP32 Dev Module" selected as board.

6. When trying to compile, I get the error:

```
In file included from /Users/xxxxx/Arduino/libraries/GxEPD-lewisxhe/GxEPD.h:20:0,
                 from /Users/xxxxx/Arduino/GxEPD_Example/GxEPD_Example.ino:10:
/Users/xxxxx/Arduino/libraries/GxEPD-lewisxhe/GxFont_GFX.h:77:13: error: 'int16_t GxFont_GFX::getUTF8Width(const char*)' cannot be overloaded
     int16_t getUTF8Width(const char *str);
             ^
/Users/xxxxx/Arduino/libraries/GxEPD-lewisxhe/GxFont_GFX.h:45:13: error: with 'int16_t GxFont_GFX::getUTF8Width(const char*)'
     int16_t getUTF8Width(const char *str);
             ^
```

Any idea how to solve this?

Thanks!

levycarneiro, 2022-02-06:
Problem solved!

See details here:
https://forum.arduino.cc/t/compiling-error-on-lilygo-2-13-epaper-display-depg0213bn/955580/4

Closed 2022-02-06.

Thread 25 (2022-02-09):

Duplicate getUTF8Width definition in lewisxhe/GxEPD causes compile errors

carl3, 2022-02-09:
There are compile errors because getUTF8Width() has duplicate definitions in the lewisxhe/GxEPD fork mentioned as a prerequisite. There is a pull request from https://github.com/bot1131357/GxEPD that fixes the bug by commenting out the duplicate definitions.

The issue cannot be reported on the  lewisxhe/GxEPD fork because issues are disabled.

If you get this compile error, then you would need to use the https://github.com/bot1131357/GxEPD version.

reppr, 2022-02-21:
This issue caused me a lot of troubles...

Why are issues disabled in the lewisxhe fork?
I cannot understand why the problem was there since sept 2021 and is still not fixed.
What should people buying this board do with it, if the supplier cannot supply working software for it?
For me it was a frustrating experience...

@LilyGO
Did LilyGo consider sending a free sample board to the main author of arduino ePaper software?

See also  https://forum.arduino.cc/t/compiling-error-on-lilygo-2-13-epaper-display-depg0213bn/955580/5

tkybundle, 2022-02-22:
I downloaded the lib here, so I was able to make 2.66 work.
https://github.com/Xinyuan-LilyGO/E-Paper-watch/tree/main/lib
anyway yeah, that sucks

lewisxhe, 2022-06-01:
I've been away for a while, since the repository is not maintained, the conflict has now been fixed, it's related to the update of the SDK

Closed 2022-06-01.

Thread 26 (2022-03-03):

T5 V2.3.1_2.13: Unknown E-Paper display, cannot find correct driver

vidhill, 2022-03-03:
I have a `LILYGO® TTGO T5 V2.3.1_2.13 Inch E-Paper Screen New Driver Chip`

The drivers for the e Ink display do not work,

I am using this example https://github.com/Xinyuan-LilyGO/LilyGo-T5-Epaper-Series/blob/master/examples/GxEPD_Example/GxEPD_Example.ino

I have the following line un-commented:
```
 #define LILYGO_T5_V213
```

I believe it is a different E-Paper display to the one referenced

The part number appears to be `WF T0213CZ16 LW`

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

I  can compile and upload,
and I can see that it is running via the serial Monitor, but the display does not update, or render anything

The sketch that was on the board did refresh, so I do not appear to have a faulty board

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

vidhill, 2022-03-07:
I have discovered that the e-paper module labeled `WF T0213CZ16 LW` is in fact [Good Display GDEW0213M21](https://www.good-display.com/product/354.html)

I needed to include the correct library which is:
```c
#elif defined(LILYGO_T5_V213)
// #include <GxDEPG0213BN/GxDEPG0213BN.h>    // 2.13" b/w  form DKE GROUP
#include <GxGDEW0213M21/GxGDEW0213M21.h>
#else
```

This driver is not included in the [GxEPD](https://github.com/ZinggJM/GxEPD) library..

I did find the right driver in randomly included in a number of github repo, https://github.com/ltsochev-dev/esp32-weather-station/tree/main/lib/GxEPD/src/GxGDEW0213M21

For anyone in the same situation as I was,
you need to install [GxEPD](https://github.com/ZinggJM/GxEPD) then copy

* `GxEPD/src/GxGDEW0213M21.h`
* `GxEPD/src/GxGDEW0213M21.cpp`
* `GxEPD/src/BitmapExamples.h`

from https://github.com/ltsochev-dev/esp32-weather-station/tree/main/lib/GxEPD/src/GxGDEW0213M21 into `GxEPD` in you Arduino libraries folder

Closed 2022-03-07.

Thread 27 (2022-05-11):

2.66 inch Lilygo T92_v1.0 support

robouden, 2022-05-11:
For the repo, support for the 2.66 inch Lilygo T92_v1.0  seems to be missing. How t add support for that board?

Regards,
Rob Oudendijk

lewisxhe, 2022-06-01:
Just uncomment `#define LILYGO_T5_V266` in the code . it should work fine

Closed 2022-06-01.

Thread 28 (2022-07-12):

Busy Timeout

Ahmedriazku2, 2022-07-12:
We have lillygo T5 board with 7.5 epaper. With a modification[Modified](https://drive.google.com/file/d/1f_AohgxSAYPVPwo2bbNI2PsKe3KxwP5s/view?usp=drivesdk)  of one spi pin 19/2 we successfully ran Waveshare[Original](https://drive.google.com/file/d/1fPD9XUesdmvl4mZLZVy-TptLoHgot-wX/view?usp=drivesdk)  weather program for two months. But since last ten days something happened, the screen went dimmed and on uploading new data sometimes it uploads but sometimes it gets stuck for days on Busy Timeout. I approached arduino forum where ZinggJM says he wont deal with Lillygo. Please do help.

lewisxhe, 2022-07-13:
You mean it's been working fine for two months? Sudden problems ten days ago?

Ahmedriazku2, 2022-07-13:
Now forget about GxEPD2 and busy timeout. Now when i run your own suggested example file the board is not updated. This is the file  i run: https://drive.google.com/open?id=1guJt0ITGjHKHFWHkqln3H-xrKVm_VhB-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
its the same as your example https://github.com/Xinyuan-LilyGO/LilyGo-T5-Epaper-Series/blob/master/examples/GxEPD_Hello_world/hello_world.ino

now the output is this:
setup
setup done
Hello World

nothing is uploaded on the epaper.

Now first fix this please. And please dont ask more questions.

lewisxhe, 2022-07-13:
I'm so sorry, this problem occurred

You can try to update the compiled binary executable to see if it is a hardware or software problem. Link:
https://github.com/Xinyuan-LilyGO/LilyGo-T5-Epaper-Series/blob/master/firmware/T5_V24_BW_GxDEPG0750BN.bin

Please use espressif flash_download_tools to flash.

https://www.espressif.com.cn/en/tools-type/flash-download-tools

For programming settings, please refer to the readme

https://github.com/Xinyuan-LilyGO/LilyGo-T5-Epaper-Series/tree/master/firmware

lewisxhe, 2022-07-15:
If it still cannot be displayed after refreshing the program, it is very likely that the board is damaged. Please send the uploading program to the board, and then manually reset the board to AliExpress customer service. It is convenient for us to deal with you after sales.

lewisxhe, 2022-08-08:
If you have any other issues, please reopen the issue

Closed 2022-08-08.

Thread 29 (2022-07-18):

Problem achieving 300uA deepsleep current on T5 2.13" v2.3.1

mgsb, 2022-07-18:
I am trying to reproduce the stated 300uA deepsleep current for the 2.13" T5 version 2.3.1 with no LEDs and the DEPG0213BN display http://www.lilygo.cn/claprod_view.aspx?TypeId=62&Id=1391&FId=t28:62:28 . I am measuring 760uA using the deepsleep example from the ESP32-C3 T-OI-Plus repo https://github.com/Xinyuan-LilyGO/LilyGo-T-OI-PLUS/blob/main/example/deepsleep/deepsleep.ino . Do you have an example I can try to reproduce your results? ESP-IDF or Arduino/PlatformIO code?

lewisxhe, 2022-07-19:
The following two sleep modes occupy different sleep currents. I remember that the sleep current of ext1 is the lowest.
```
esp_sleep_disable_wakeup_source(ESP_SLEEP_WAKEUP_TIMER);
esp_sleep_enable_ext1_wakeup(GPIO_NUM, ESP_EXT1_WAKEUP_ALL_LOW);
esp_sleep_enable_ext0_wakeup(GPIO_NUM, 0);
```

lewisxhe, 2022-08-08:
If you have any other issues, please reopen the issue

Closed 2022-08-08.

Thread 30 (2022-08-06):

T5 2.9” V2.2 Deep Sleep Issue

cvocvo, 2022-08-06:
I’m using ESPHome with a T5 2.9” v2.2 epaper, and when I enter deep sleep — shortly after entering deep sleep my screen becomes weird — half white / half black display with artifacts. I will try to post a picture.

The refresh will occur in deep sleep but the display itself won’t recover.

Any ideas? Is deep sleep supported on v2.2?

cvocvo, 2022-08-06:
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

lewisxhe, 2022-08-08:
T5_V2.2 supports deep sleep. If the screen is refreshed after deep sleep is set, please check what is the reason for waking up. I don't use ESPHome. I will rule out the reason for the time being. you can refresh

https://github.com/Xinyuan-LilyGO/LilyGo-T5-Epaper-Series/blob/master/examples/GxEPD_Example/GxEPD_Example.ino

Check if you can sleep normally

cvocvo, 2022-08-08:
I think you're spot on -- I played with the refresh settings a little bit and found a post with a similar issue here: https://github.com/esphome/issues/issues/2334

Once I get it dialed in, I'll post some code this week or this weekend.

cvocvo, 2022-08-11:
I think I got it mostly sorted out; battery life still isn't great but that's a known limitation of v2.2 of the 2.9" board.
Here's what I've got for code -- I solved a bunch of problems (screen reloading issue, deep sleep, sleeping the flash, button to reload, etc.) and posted code up here: https://github.com/cvocvo/esphomeprojects/blob/main/epaper29.yaml

Closed 2022-08-11.

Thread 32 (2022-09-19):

Battery charge %

alfwro13, 2022-09-19:
Hi,
I have LILYGO® TTGO T5 V2.3 2.13 Inch E-Paper Screen and I have connected 3.7v 300mAh battery to the onboad battery connector.
I can see that on the board text written next to the battery connector BAT_TEST_35. What is it and can I use that to calculate battery % charge?

lewisxhe, 2022-09-21:
Yes, IO35 can collect battery voltage

alfwro13, 2022-09-26:
and is there a way to calculate the battery % charge ?

lewisxhe, 2022-09-28:
You can refer to this code

https://github.com/lewisxhe/XPowersLib/blob/master/src/XPowersAXP192.tpp#L1441-L1441

BatsIhor, 2022-12-07:
`   float voltage = analogRead(35) / 4096.0 * 7.46;
    uint8_t percentage = 100;
    if (voltage > 1)
    { // Only display if there is a valid reading
        Serial.println("Voltage = " + String(voltage));
        percentage = 2836.9625 * pow(voltage, 4) - 43987.4889 * pow(voltage, 3) + 255233.8134 * pow(voltage, 2) - 656689.7123 * voltage + 632041.7303;
        if (voltage >= 4.20)
            percentage = 100;
        if (voltage <= 3.50)
            percentage = 0;
        Serial.println("Percentage = " + String(percentage));
}`

BatsIhor, 2023-09-05:
@lewisxhe I checked your link but it's not clear how to use XPowerLib and what is the purpose of it. Do you have any documentation on what it is and when to use it? I was not able to find anything on the internet yet.

lewisxhe, 2023-09-06:
No, I'm just giving you a rough calculation of the percentage. Although it's not accurate, it can achieve the desired effect.

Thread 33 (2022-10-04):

SD card reader not working [T5_V2.3.1_213] (20-8-26)

mrWheel, 2022-10-04:
Hi,

I changed this code:
<pre>
String sizeString = "SD:" + String(SD.cardSize() / 1024.0 / 1024.0 / 1024.0) + "G";
</pre>
to:
<pre>
String sizeString = "SD:" + String(SD.cardSize() / 2048.0 / 2048.0 / 2048.0) + "G";
</pre>
and just to be sure added this line of code:
<pre>
Serial.printf("SD: %dG\r\n", SD.cardSize());
</pre>
If I insert a 2GB microSD card  `SD.cardSize()` returns zero.

I checked the defines with the silkscreen on my board and that all looks good/normal.
The SD card works OK on other devices.

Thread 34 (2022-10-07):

Open to reorganize LilyGo-specific library

rrainey, 2022-10-07:
I have encountered several recent issues keeping the LilyGo specific enhancements to the standard GxEPD library synchronized and up-to-date. It's just not very clean to be manually copying the LilyGo "lib" folder into the Arduino libraries tree by hand. I have a proposal: how about pulling boards.h and associated LilyGo-specific subfolders into a fresh library that logically lays atop GxEPD rather than trying to maintain a separate fork? This new library would be constructed as a standard Arduino library, so the extra dependent libraries could be declared as such.

What are your thoughts on this?

mrWheel, 2022-10-07:
YES!

I'm for it!

I totally removed the `boards.h` file and included the definitions for my board in de sketch.

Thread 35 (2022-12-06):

Is there a way to check it charger is connected?

BatsIhor, 2022-12-06:
Hi there,
On other boards I used battery pin to check voltage and in case it's more than 4.3V I assume usb cable is connected.
But is there other way to make sure charger is connected?
My problem is that some cheap cables and chargers deliver less than 4.3V and in that case device goes to sleep while still on charger.

Thank you
Ihor

lewisxhe, 2022-12-10:
Based on the current circuit, it is impossible to accurately determine whether USB is inserted

Closed 2022-12-10.

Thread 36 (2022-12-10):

Boards.h

Rolzzz, 2022-12-10:
All of your examples fail with the following

"Please edit Boards.h with a hardware abstraction for this board"

lewisxhe, 2022-12-10:
The sketch is compatible with multiple boards, each board has different pin definitions, and the model used needs to be defined above the sketch.
https://github.com/Xinyuan-LilyGO/LilyGo-T5-Epaper-Series/blob/4ad1172a7157b26640b1d359717f24ae34e61af7/examples/GxEPD_Example/GxEPD_Example.ino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

Rolzzz, 2022-12-10:
> The sketch is compatible with multiple boards, each board has different pin definitions, and the model used needs to be defined above the sketch.
>
> https://github.com/Xinyuan-LilyGO/LilyGo-T5-Epaper-Series/blob/4ad1172a7157b26640b1d359717f24ae34e61af7/examples/GxEPD_Example/GxEPD_Example.ino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

I got GxEPD_Example.ino compiled and uploaded but my e-paper isn't functioning, I've emailed support to assist before I can try again

parahooners, 2022-12-28:
Hey - Try and roll back your board manager in Arduino - to 2.0.1 this worked for me

parahooners, 2022-12-28:
i also found that the below worked well with my screen even tho all the setups say use another

#include <GxGDEH0213B73/GxGDEH0213B73.h>  // 2.13" b/w  old panel , form GoodDisplay

Rolzzz, 2022-12-28:
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

support got back to me and showed me to load right FW for board and I got screen working again.

For the Boards.h issue, I also got this worked out.

There are multiple B(b)oards.h files, one is upper case and one is lower case.

once I had both files in different areas read by Arduino IDE plus I had to comment out the first 2 lines of this set and uncomment the next lot then it all worked.

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

Closed 2022-12-28.

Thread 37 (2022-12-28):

issue with ESP32 Board Manager - EPAPER - Arduino - Board Manager

parahooners, 2022-12-28:
Hey just a head up that when using IDE - you will need to roll back the board manager to an earlier version - there is a bug which stops the Epaper boards from working on the newer FW in IDE

Closed 2023-01-27.

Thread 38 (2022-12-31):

T5 V2.3 battery connector type?

masterzen, 2022-12-31:
Hi!
It's not really an issue, but I was wondering what kind of JST (if that's one) connector is used to plug a battery to a T5 V2.3?

Thanks,

lewisxhe, 2023-01-03:
MX1.25MM-2P

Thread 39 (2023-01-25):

Step files

Metatron2k2, 2023-01-25:
I just wanted to ask if it is possible to add step files to the repository. Sorry for raising an issue.

lewisxhe, 2023-01-27:
What does a step file mean?

Metatron2k2, 2023-01-27:
Step file is the 3d Model. It can be created from the original board layout and would be super helpful for constructing 3D cases as we don't have to measure every dimension of the components.

27.01.2023 05:39:12 lewis he ***@***.***>:

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

lewisxhe, 2023-01-27:
Which one do you need? As far as I know, not every model has 3D files. I need to find someone to get these files. If I get these files, I will upload them

Metatron2k2, 2023-01-27:
T5 V2.3 would be awesome!

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

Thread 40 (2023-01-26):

Identify LilyGo-T5-Epaper version -> not available on website nor board

maxbrito500, 2023-01-26:
There exists no identification of the version either on the purchase page nor the board.

There is also no straightforward way to identify the screen model.

The problem is that guessing the board and screen is **not** working. Furthermore, this is a 4.7" screen and there is no driver mentioned there for that model. They are all smaller or bigger.

Purchase page is here: https://www.aliexpress.com/item/1005002272417292.html

If someone can help it would be appreciated.

Developers:
Please consider outputting the board version/details through the serial port with the default firmware. This would already save a lot of difficulty to get this information.

Many thanks!

lewisxhe, 2023-01-27:
The board you buy should correspond to this link:
https://github.com/Xinyuan-LilyGO/LilyGo-EPD47

maxbrito500, 2023-01-27:
Oh my. Thank you!

I got confused and assumed this was the repository for all ePaper modules. Topic solved.

Closed 2023-01-27.

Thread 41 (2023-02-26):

[Linux] Module needed to flash T5?

Shohreh, 2023-02-26:
Hello,

I ordered a ["DEPG0213BN 9102 Chip" T5](https://www.aliexpress.com/item/32869729970.html), altough it says "CH9102F" on the actual hardware I got, and it says "CH340" when connected to Linux.

I can reflash the board successfully on Windows using a web-based flasher.

On Linux, after successuflly compiling a project, it fails flashing the board: "Detecting chip type... Unsupported detection protocol, switching and trying again... Detecting chip type... ESP32-S2".

Is a module needed on Linux?

Thank you.

```
-bash-5.1# lsusb
Bus 001 Device 003: ID 058f:6366 Alcor Micro Corp. Multi Flash Reader
Bus 001 Device 001: ID 1d6b:0002 Linux Foundation 2.0 root hub
Bus 002 Device 005: ID 1a86:55d4 QinHeng Electronics USB Single Serial
Bus 002 Device 002: ID 1a86:7523 QinHeng Electronics CH340 serial converter
Bus 002 Device 001: ID 1d6b:0001 Linux Foundation 1.1 root hub

-bash-5.1# ll /dev/ttyU*
crw-rw---- 1 root dialout 188, 0 Feb 26 20:47 /dev/ttyUSB0

-bash-5.1# idf.py flash /dev/ttyUSB0
Executing action: flash
Serial port /dev/ttyUSB0
Connecting.........
Detecting chip type... Unsupported detection protocol, switching and trying again...
Detecting chip type... ESP32-S2
Running ninja in directory /root/esp/esp-idf/AirMeter.IO.Firmware/build
Executing "ninja flash"...
[1/7] Performing build step for 'bootloader'
[1/1] cd /root/esp/esp-idf/AirMeter.IO.Firmware/build/bootloader/esp-idf/esptool_py && /root/.espressif/python_env/idf5.0_py3.9_env/bin/python /root/esp/esp-idf/components/partition_table/check_sizes.py --offset 0x8000 bootloader 0x1000 /root/esp/esp-idf/AirMeter.IO.Firmware/build/bootloader/bootloader.bin
Bootloader binary size 0x57a0 bytes. 0x1860 bytes (22%) free.
[2/5] cd /root/esp/esp-idf/AirMeter.IO.Firmware/build/esp-idf/esptool_py && /root/.espressif/python_env/idf5.0_py3.9_env/bin/python /root/esp/esp-idf/components/partition_table/check_sizes.py --offset 0x8000 partition --type app /root/esp/esp-idf/AirMeter.IO.Firmware/build/partition_table/partition-table.bin /root/esp/esp-idf/AirMeter.IO.Firmware/build/main.bin
main.bin binary size 0xde0f0 bytes. Smallest app partition is 0x100000 bytes. 0x21f10 bytes (13%) free.
[3/5] cd /root/esp/esp-idf/AirMeter.IO.Firmware/build/esp-idf/main && /root/.espressif/python_env/idf5.0_py3.9_env/bin/python /root/esp/esp-idf/components/spiffs/spiffsgen.py 0x1e000 /root/esp/esp-idf/AirMeter.IO.Firmware/device /root/esp/esp-idf/AirMeter.IO.Firmware/build/dev.bin --page-size=256 --obj-name-len=32 --meta-len=4 --use-magic --use-magic-len
[4/5] cd /root/esp/esp-idf/AirMeter.IO.Firmware/build/esp-idf/main && /root/.espressif/python_env/idf5.0_py3.9_env/bin/python /root/esp/esp-idf/components/spiffs/spiffsgen.py 0xc8000 /root/esp/esp-idf/AirMeter.IO.Firmware/webui/distgz /root/esp/esp-idf/AirMeter.IO.Firmware/build/web.bin --page-size=256 --obj-name-len=32 --meta-len=4 --use-magic --use-magic-len
[4/5] cd /root/esp/esp-idf/components/esptool_py && /usr/bin/cmake -D IDF_PATH=/root/esp/esp-idf -D "SERIAL_TOOL=/root/.espressif/python_env/idf5.0_py3.9_env/bin/python;;/root/esp/esp-idf/components/esptool_py/esptool/esptool.py;--chip;esp32" -D "SERIAL_TOOL_ARGS=--before=default_reset;--after=hard_reset;write_flash;@flash_args" -D WORKING_DIRECTORY=/root/esp/esp-idf/AirMeter.IO.Firmware/build -P /root/esp/esp-idf/components/esptool_py/run_serial_tool.cmake
esptool esp32 -p /dev/ttyUSB0 -b 460800 --before=default_reset --after=hard_reset write_flash --flash_mode dio --flash_freq 40m --flash_size 4MB 0x1000 bootloader/bootloader.bin 0x10000 main.bin 0x8000 partition_table/partition-table.bin 0xd000 ota_data_initial.bin 0x22e000 web.bin 0x2f6000 dev.bin
esptool.py v4.5
Serial port /dev/ttyUSB0
Connecting..........

A fatal error occurred: This chip is ESP32-S2 not ESP32. Wrong --chip argument?
CMake Error at run_serial_tool.cmake:55 (message):

  /root/.espressif/python_env/idf5.0_py3.9_env/bin/python;;/root/esp/esp-idf/components/esptool_py/esptool/esptool.py;--chip;esp32
  failed

FAILED: CMakeFiles/flash
cd /root/esp/esp-idf/components/esptool_py && /usr/bin/cmake -D IDF_PATH=/root/esp/esp-idf -D "SERIAL_TOOL=/root/.espressif/python_env/idf5.0_py3.9_env/bin/python;;/root/esp/esp-idf/components/esptool_py/esptool/esptool.py;--chip;esp32" -D "SERIAL_TOOL_ARGS=--before=default_reset;--after=hard_reset;write_flash;@flash_args" -D WORKING_DIRECTORY=/root/esp/esp-idf/AirMeter.IO.Firmware/build -P /root/esp/esp-idf/components/esptool_py/run_serial_tool.cmake
ninja: build stopped: subcommand failed.
ninja failed with exit code 1, output of the command is in the /root/esp/esp-idf/AirMeter.IO.Firmware/build/log/idf_py_stderr_output_10554 and /root/esp/esp-idf/AirMeter.IO.Firmware/build/log/idf_py_stdout_output_10554
```

lewisxhe, 2023-02-27:
On my Ubuntu, it is not ttyUSB
, but ttyACM0, please check whether the correct port is selected
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

Shohreh, 2023-02-27:
Thanks for the tip. dmesg -wH does show a /dev/ttyACM0 device popping up.

But flashing fails, regardless of the board being ON or OFF:

```
echo "alias get_idf='. $HOME/esp/esp-idf/export.sh'" >> ~/.bashrc
source ~/.bashrc

get_idf

cd ~/esp/esp-idf/AirMeter.IO.Firmware
-bash-5.1# idf.py /dev/ttyACM0 flash
Executing action: /dev/ttyACM0
ninja: error: unknown target '/dev/ttyACM0'
command "/dev/ttyACM0" is not known to idf.py and is not a Ninja target
```

lewisxhe, 2023-02-27:
Are you using idf? You should specify the port like this

```
idf.py -p /dev/tty.ttyACM0 -b 115200 flash

```

Shohreh, 2023-02-27:
Flashing does seem to work with the command I used.

lewisxhe, 2023-02-27:
If the problem is solved, the problem will be closed

Closed 2023-02-27.

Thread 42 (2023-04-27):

my T5 does not connect with usb port. as in the picture

allisonwilliancandido, 2023-04-27:
I'm trying to connect lilygo but windows 10 doesn't recognize the device.
image attached
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

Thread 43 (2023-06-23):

USB disconnects after a few seconds

ramatomo, 2023-06-23:
T5-4,7 S3 on Windows 10
I tried to load first sketch with arduino ide, OWM_EPD47_epaper_v2.5, no error.
However, the screen remained that of the newly purchased device, I tried to reload the sketch but it gave me some errors, after a few times the screen began to disconnect from the USB after a few seconds. I've tried updating USB drivers, changing cables, but to no avail.

ramatomo, 2023-06-26:
thanks

Closed 2023-06-26.

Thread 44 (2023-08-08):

Unable to communicate with T5 v2.3.2 using T-U2T

StevenCellist, 2023-08-08:
Hi guys, I got my hand on a brand-new TTGO T5 v2.3.2 with 2.13 inch e-ink display (not yet released in lilygo.cc but available through reseller).
As per my reseller, the difference w.r.t. v2.3.1 is the need to use the T-U2T to program the board.
This is confirmed by plugging a USB-A to USB-C cable straight into the board: Windows Device Manager doesn't show any port, while the board is being powered and running the example sketch.

When I plug just the T-U2T into my USB cable, Device Manager shows `USB-SERIAL CH340K (COM10)`, indicating that the adapter is working nicely. However, when I plug it into the board, I get no communication at all. When I reset the board using RST button, nothing. When uploading a sketch and pressing BOOT on the U2T, "no serial data received". When holding BOOT and pressing and releasing RST, "no serial data received". I tried another machine, another cable (which did work on other USB-C boards) - no bit of luck.

How should I go about communicating with and programming this device? What could I try? Is there any documentation for this new version 2.3.2?

Attached are pictures of the board, in case that someone wants to look at it.
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

StevenCellist, 2023-08-09:
@lewisxhe thanks for your reply.  I uninstalled the drivers for the specific COM port through Device manager, rebooted and installed your linked drivers. I should note that the installer also shows "CH34SER.INF" as driver name.
Once I connect the U2T, the CH340K name comes back up. And per [this](https://forum.arduino.cc/t/lilygo-ttgo-ch9102f-chip-windows-drivers/949744/5) post, that should work just fine. But still no response from the T5 v2.3.2 :(
Could there be anything else that I'm doing wrong?

lewisxhe, 2023-08-09:
Do you use Windows?

lewisxhe, 2023-08-10:
try this driver
[CH9102.zip](https://github.com/Xinyuan-LilyGO/LilyGo-T5-Epaper-Series/files/12307856/CH9102.zip)

StevenCellist, 2023-08-10:
Did the following:
- uninstall device and check "remove drivers" from Device Manager
- remove U2T
- reboot
- install the .exe
- reboot
- plug in U2T
- Device Manager at first doesn't recognize, just lists "USB Serial"
- after a couple seconds, it apparently installs the drivers and again: CH340K
:( sorry to make this so complicated.. PC is stubborn!

lewisxhe, 2023-08-10:
If it recognizes 340K, then it is really possible that it is 340K.

You try to insert U2T into the board and connect it to the computer via USBC, then open Serial, and click the RST of the board to see what information is output.

lewisxhe, 2023-08-10:
Can the USB screen be updated by inserting it?

StevenCellist, 2023-08-10:
What exactly do you mean by that?
The device does power up and shows the out-of-the-box example animation of squares in the corners, showing all available characters etc.

lewisxhe, 2023-08-10:
Okay, contact the seller and have them send you a new U2T.

StevenCellist, 2023-08-12:
Yes, the 'old' one was not correct! I got sent a new one - the sticker on the box is marked completely different and it shows up as CH9102, and I can successfully read serial information now!

In case anyone ends up here: my incorrectly working one had the box marked with H494, while the working one is marked with Q320 and CH9102F as well.

@lewisxhe thanks for the debugging and thinking along!!

Closed 2023-08-12.

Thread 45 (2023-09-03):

Which driver should I use? Seems none from Hello World example works

tomasz90, 2023-09-03:
On some drivers display is refreshing, but nothing is really displayed.

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

lewisxhe, 2023-09-03:
https://github.com/Xinyuan-LilyGO/LilyGo-T5-Epaper-Series/blob/master/examples/GxEPD_Example/GxEPD_Example.ino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

Board select T5_V21V in sketch

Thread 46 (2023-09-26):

SD card  not working when using T5_V2.3.1_213]

bruno1950, 2023-09-26:
Hi,
I just bought  a Lilygo T5 V2.3.1.213 version GDEM0213B74 CH9102 and I was able to show on display data from I2C sensors (BME280 and SHT3x) and to get a timestamp from RTC DS3231. Deepsleep also works fine. However, I was not able to use the SD card, neither inserting it directly in the slot nor connected to an external SDcard reader ( MOSI IO15,MISO IO2, SCK IOIO14, CS IO13). The card is correctly mounted  but I keep on gettin an error "opening the file" or ""appending the file". Even using a vey simple sketch just to try if it's possible to write something on the SD card is unsuccesful. Since I think that Lilygo is a good brand I have to assume that it's my fault but I was not able to find my mistake. Could anyone tell me which code I have to use just to write data on SD card in order to use it as a datalogger ? Thx in advance

lewisxhe, 2023-09-27:
Please copy your sketch here

bruno1950, 2023-10-01:
Hi,

sorry for the long delay in answering your request but I was in hospital for a programmed surgery that luckily went fine.

Here you have the sketch that doesn't work for what attains the SD card since on the serial monitor I get the message "opening file failed" and "appending file failed" and no data are saved on the SD

When I use this sketch ( clearly with needed modifications) wth the TFT Lilygo board it works just fine.

Thx for your hekp

Bruno

#include <SD.h>
#include <FS.h>

#include <SPI.h>
#include <Wire.h>

#include <RTClib.h> // for the RTC
RTC_DS3231 rtc;

#include <GxFont_GFX.h>

#include <GxEPD2.h>
#include <GxGDEM0213B74/GxGDEM0213B74.h> // specific gor the Lilygo eink display model I have

#include <Fonts/FreeMonoBold9pt7b.h>

#include <GxIO/GxIO_SPI/GxIO_SPI.h>
#include <GxIO/GxIO.h>

#define SPI_MOSI 23
#define SPI_MISO -1
#define SPI_CLK 18
#define ELINK_SS 5
#define ELINK_BUSY 4
#define ELINK_RESET 16
#define ELINK_DC 17

#define SDCARD_SS 13
#define SDCARD_CLK 14
#define SDCARD_MOSI 15
#define SDCARD_MISO 2

GxIO_Class io(SPI, /*CS=5*/ ELINK_SS, /*DC=*/ ELINK_DC, /*RST=*/ ELINK_RESET);
GxEPD_Class display(io, /*RST=*/ ELINK_RESET, /*BUSY=*/ ELINK_BUSY);

SPIClass sdSPI(VSPI);

bool sdOK = false;

#include <Adafruit_Sensor.h>
#include <Adafruit_BME280.h>

#define SEALEVELPRESSURE_HPA (1013.25)
Adafruit_BME280 bme; // I2C

#include <SHT3x.h>
SHT3x Sensor;

// variables to store data from sensors ( float type because they are value with a decimal part)

float TEMP;
float HUM;
float temp;
float hum;

String timeStamp;

String Data;

// variables to define sleep time; the first multiplies the value to get seconds from microseconds; the second says the sleep time in seconds (900 = 15 minutes)
uint64_t uS_TO_S_FACTOR = 1000000;
uint64_t TIME_TO_SLEEP = 900; //sleep for 15 minutes

String dataMessage;

void print_wakeup_reason(){
esp_sleep_wakeup_cause_t wakeup_reason;

wakeup_reason = esp_sleep_get_wakeup_cause();

switch(wakeup_reason)
{
case ESP_SLEEP_WAKEUP_EXT0 : Serial.println("Wakeup caused by external signal using RTC_IO"); break;
case ESP_SLEEP_WAKEUP_EXT1 : Serial.println("Wakeup caused by external signal using RTC_CNTL"); break;
case ESP_SLEEP_WAKEUP_TIMER : Serial.println("Wakeup caused by timer"); break;
case ESP_SLEEP_WAKEUP_TOUCHPAD : Serial.println("Wakeup caused by touchpad"); break;
case ESP_SLEEP_WAKEUP_ULP : Serial.println("Wakeup caused by ULP program"); break;
default : Serial.printf("Wakeup was not caused by deep sleep: %d\n",wakeup_reason); break;
}
}

// setting a counter for data readings; it will increase every time data from sensors are collected
RTC_DATA_ATTR int sensor_data = 0;

#define sensor_data(temp,hum,TEMP,HUM);

// to get time from RTC
void gettimeStamp() {
DateTime now = rtc.now();

char timeStamp[9];
sprintf(timeStamp, "%02i:%02i:%02i", now.hour(), now.minute(), now.second());

Serial.println(timeStamp);
}

// to print on serial monitor data from sensors
void Read_TempHum()
{
Serial.print("Temp_BME280 = ");
Serial.print(temp);
Serial.println(" C");
Serial.print("Hum_BME280 = ");
Serial.print(hum);
Serial.println(" %");
Serial.print("Temp_SHT3x = ");
Serial.print(TEMP);
Serial.println(" C");
Serial.print("Hum_SHT3X = ");
Serial.print(HUM);
Serial.println(" %");
Serial.print(timeStamp);
}

//to display on Eink display data
void displayReadings(){
DateTime now = rtc.now();
char timeStamp[9];
sprintf(timeStamp, "%02i:%02i:%02i", now.hour(), now.minute(), now.second());
display.setCursor(0,0);
display.setTextColor(GxEPD_BLACK);
display.setCursor(0,20);
display.print("temp_BME = ");
display.print(temp);
display.println(" C");
display.print("temp_SHT = ");
display.print(TEMP);
display.println(" C");
display.print("hum_BME = ");
display.print(hum);
display.println(" %");
display.print("hum_SHT = ");
display.print(HUM);
display.println(" %");
display.setCursor(0,100);
display.print(timeStamp);
display.setCursor(100,100);
display.print("Run n ");
display.println(sensor_data);
display.setCursor(0,115);
display.print("Now sleep for 15 min");

display.update();
}

// to save data on SDcard
void logSDCard() {
DateTime now = rtc.now();
char timeStamp[9];
sprintf(timeStamp, "%02i:%02i:%02i", now.hour(), now.minute(), now.second());
dataMessage = String(timeStamp) + "\r\n";
dataMessage = String(timeStamp) + "," +
String(temp) + "," + String(hum)+ "," + String(TEMP) + "," + String(HUM) +"\r\n";
Serial.print("Save data: ");
Serial.println(dataMessage);
appendFile(SD, "/data.txt", dataMessage.c_str());
}

// Write to the SD card
void writeFile(fs::FS &fs, const char * path, const char * message) {
Serial.printf("Writing file: %s\n", path);
File file = fs.open(path, FILE_WRITE);
if(!file) {
Serial.println("Failed to open file for writing");
return;
}
if(file.print(message)) {
Serial.println("File written");
} else {
Serial.println("Write failed");
}
file.close();
}
// Append data to the SD card
void appendFile(fs::FS &fs, const char * path, const char * message) {
Serial.printf("Appending to file: %s\n", path);
File file = fs.open(path, FILE_APPEND);
if(!file) {
Serial.println("Failed to open file for appending");
return;
}
if(file.print(message)) {
Serial.println("Message appended");
} else {
Serial.println("Append failed");
}
file.close();
}

void setup()
{
Serial.begin(115200);
while(!Serial);
delay(100);

// checking the BME280 connections and initializing the sensor
bool status;
status = bme.begin(0x76);
if (!status) {
Serial.println("Could not find a valid BME280 sensor, check wiring!");
while (1);
}

//initializing SD card
sdSPI.begin(SDCARD_CLK, SDCARD_MISO, SDCARD_MOSI, SDCARD_SS);
if (!SD.begin(SDCARD_SS, sdSPI)) {
sdOK = false;
} else {
sdOK = true;
}

Serial.println("SDcard initialized!!");
delay(500);
File file = SD.open("/data.txt");
if(!file) {
Serial.println("File doens't exist");
Serial.println("Creating file...");
writeFile(SD, "/data.txt", "Time, Temperature, Humidity,TEMP,HUM, \r\n");
}
else {
Serial.println("File already exists");
}
file.close();

//initializing the SHT31 sensor
Sensor.Begin();
Sensor.UpdateData();
TEMP = Sensor.GetTemperature();
HUM = Sensor.GetRelHumidity();

delay(100);

// setup for the RTC
if(! rtc.begin()) {
Serial.println("Couldn't find RTC");
while (1);
}
else {
// following line sets the RTC to the date & time this sketch was compiled
rtc.adjust(DateTime(F(__DATE__), F(__TIME__)));
}

temp = bme.readTemperature();
hum = bme.readHumidity();

SPI.begin(SPI_CLK, SPI_MISO, SPI_MOSI, ELINK_SS);
display.init(); // enable diagnostic output on Serial
display.setRotation(1);
display.fillScreen(GxEPD_WHITE);
display.setTextColor(GxEPD_BLACK);
display.setFont(&FreeMonoBold9pt7b);
display.setCursor(0, 0);
delay(1500);

display.update();

Read_TempHum();
displayReadings();
logSDCard();

// increasing the counter for the next data readings

sensor_data++;

Serial.println("Sensor data logged successfully! Going to sleep");

// ESP32 going to sleep for the amount of time you decided
esp_sleep_enable_timer_wakeup(TIME_TO_SLEEP * uS_TO_S_FACTOR);
delay(5000);
esp_deep_sleep_start();

delay(2000);
esp_deep_sleep_start();
}

void loop()
{}

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

lewisxhe, 2023-10-04:
It seems that there is no problem with the SD part. Has the SD card been formatted in FAT32 format? Is the capacity less than 32G? Have you replaced any other SD tests?

bruno1950, 2023-10-04:
Hi, thx for your prompt feedback.
I tried with two different SDcard-adapters and with two different SD cards, one with 4 Gb and the other with 16 Gb, both formatted FAT32, but I still have the same error "Failed to open file for appending"
If I use codes devised to test SDcard (such as the SD_test.ino) I get the error message "Card Mount Failed" both when I insert the card in the slot of the board and if I use an external SD-card reader connected according to instructions.
At this point  one question and one request.
Question: Have you tried to run my sketch ( or a similar one with data collected from an I2C sensor) with SD card on a Lilygo T5_V2.3.1_213 ? Were you successful ?
Request: Would you be so kind to send me  a working code for using SD card  as a data logger with this board ? I was not able to find any simple example of this use  and I need to save on SDcard data collected from an I2C sensor.
Otherwise this board is of no use for me.
 Thx for your help.

lewisxhe, 2023-10-07:
Use the factory test file to test to see if it is normal @bruno1950
[firmware](https://github.com/Xinyuan-LilyGO/LilyGo-T5-Epaper-Series/tree/master/firmware)

bruno1950, 2023-10-17:
Hi,
I tried to use the file factory test as you suggested but I was not able to get a result even following your example.
For firmware I downloaded the [T5_V24_BW_GxGDEM0213B74.bin] because my board is this type. Then I downloaded from Espressif site the ESP32 FLASH DOWNLOAD TOOL but the available version is different from your example and I am blocked. I'm enclosing the pictutes of what I'm getting.
I've also tried to use your SD_test.ino but I got a lot of errors and it doesn't work.
Since I'm a newbie could you you please send me a code for SD card working for my Lilygo board ? or at least telling me where I can find it ?
I've seen that my issue was raised also last year by another user and seems NOT to have been solved (https://github.com/Xinyuan-LilyGO/LilyGo-T5-Epaper-Series/issues/33)

Thanks in advance for your help. The board would be perfect IF the SD card worked
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

lewisxhe, 2023-10-19:
You have burned the wrong firmware, you should have burned
[T5_V213_BW_GxGDEM0213B74.bin](https://github.com/Xinyuan-LilyGO/LilyGo-T5-Epaper-Series/blob/master/firmware/T5_V213_BW_GxGDEM0213B74.bin)

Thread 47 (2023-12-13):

I cannot clear T5 2.31_2.13 display

zsiroslaci, 2023-12-13:
I made a program which wrote text on it. But the text written on display cannot be removed. New text written by new program over write it so the old text pixels and the one  both displayed. The new text  is removable, but the old one cannot.

What can I do to remove old text?

Br
Laszlo

lewisxhe, 2023-12-15:
Is it as if the font is permanently printed on the screen?

zsiroslaci, 2023-12-15:
<!--
/* Font Definitions */
@font-face
	{font-family:"Cambria Math";
	panose-1:2 4 5 3 5 4 6 3 2 4;}
@font-face
	{font-family:Calibri;
	panose-1:2 15 5 2 2 2 4 3 2 4;}
/* Style Definitions */
p.MsoNormal, li.MsoNormal, div.MsoNormal
	{margin:0cm;
	font-size:11.0pt;
	font-family:"Calibri",sans-serif;}
a:link, span.MsoHyperlink
	{mso-style-priority:99;
	color:blue;
	text-decoration:underline;}
span.DefaultFontHxMailStyle
	{mso-style-name:"Default Font HxMail Style";
	font-family:"Calibri",sans-serif;
	color:windowtext;
	font-weight:normal;
	font-style:normal;
	text-decoration:none none;}
.MsoChpDefault
	{mso-style-type:export-only;}
@page WordSection1
	{size:612.0pt 792.0pt;
	margin:70.85pt 70.85pt 70.85pt 70.85pt;}
div.WordSection1
	{page:WordSection1;}
-->Yes. It is permanently printed on the screen.Whath can I do with it?BrLaszlo Küldte a Windows Posta Feladó: Lewis HeElküldve: 2023. december 15., péntek 3:10Címzett: Xinyuan-LilyGO/LilyGo-T5-Epaper-SeriesMásolatot kap: zsiroslaci; AuthorTárgy: Re: [Xinyuan-LilyGO/LilyGo-T5-Epaper-Series] I cannot clear T5 2.31_2.13 display (Issue #47) Is it as if the font is permanently printed on the screen?—Reply to this email directly, view it on GitHub, or unsubscribe.You are receiving this because you authored the thread.Message ID: ***@***.***>

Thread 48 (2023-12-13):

[DEPG0266BN] spiram: SPI RAM not initialized

iw0der, 2023-12-13:
Hi,
I'm experiencing some errors on the hardware module LILYGO® TTGO T5 2.66-Inch E-Paper. Now I want to report here the first problem encountered!

I try to use/enable the external RAM via Arduino IDE but I only get crashes, at most I get to this:

```
Rebooting...
ets Jul 29 2019 12:21:46

rst:0xc (SW_CPU_RESET),boot:0x13 (SPI_FAST_FLASH_BOOT)
configsip: 0, SPIWP:0xee
clk_drv:0x00,q_drv:0x00,d_drv:0x00,cs0_drv:0x00,hd_drv:0x00,wp_drv:0x00
mode:DIO, clock div:1
load:0x3fff0030,len:1344
load:0x40078000,len:13964
load:0x40080400,len:3600
entry 0x400805f0
E (298) spiram: SPI RAM not initialized

abort() was called at PC 0x401027b7 on core 0

Backtrace: 0x400838cd:0x3ffe3af0 0x4008d1cd:0x3ffe3b10 0x400926cd:0x3ffe3b30 0x401027b7:0x3ffe3bb0 0x401027f7:0x3ffe3bd0 0x401026cb:0x3ffe3bf0 0x400e5623:0x3ffe3c20 0x40082fe1:0x3ffe3c50 0x40079316:0x3ffe3c90 |<-CORRUPTED

ELF file SHA256: ee06d735f4dcf31a
```

I chose the ESP32 Wrover Kit as the compilation template but I also tried other combinations... I chose psram enable but when I run the code it gives an error like the one reported.

Am I forgetting some steps or do I have a problem with recognizing the external RAM?

At boot it seems that it is not detected and the crash reports library functions even before my setup:
```
0x400838cd: panic_abort at /Users/ficeto/Desktop/ESP32/ESP32S2/esp-idf-public/components/esp_system/panic.c line 408
0x4008d1cd: esp_system_abort at /Users/ficeto/Desktop/ESP32/ESP32S2/esp-idf-public/components/esp_system/esp_system.c line 137
0x400926cd: abort at /Users/ficeto/Desktop/ESP32/ESP32S2/esp-idf-public/components/newlib/abort.c line 46
0x401027b7: esp_spiram_get_chip_size at /Users/ficeto/Desktop/ESP32/ESP32S2/esp-idf-public/components/esp_hw_support/port/esp32/spiram.c line 145
0x401027f7: esp_spiram_get_size at /Users/ficeto/Desktop/ESP32/ESP32S2/esp-idf-public/components/esp_hw_support/port/esp32/spiram.c line 241
0x401026cb: esp_himem_init at /Users/ficeto/Desktop/ESP32/ESP32S2/esp-idf-public/components/esp_hw_support/port/esp32/esp_himem.c line 134
0x400e5623: start_cpu0_default at /Users/ficeto/Desktop/ESP32/ESP32S2/esp-idf-public/components/esp_system/startup.c line 201
0x40082fe1: call_start_cpu0 at /Users/ficeto/Desktop/ESP32/ESP32S2/esp-idf-public/components/hal/esp32/include/hal/cpu_ll.h line 39

```

Thanks

73,
Arturo.

iw0der, 2023-12-13:
With board "ESP32 Wrover kit (all version)" and an if that uses psramInit() it doesn't crash, but it still says it can't see the external RAM!

```
ets Jul 29 2019 12:21:46

rst:0x1 (POWERON_RESET),boot:0x13 (SPI_FAST_FLASH_BOOT)
configsip: 0, SPIWP:0xee
clk_drv:0x00,q_drv:0x00,d_drv:0x00,cs0_drv:0x00,hd_drv:0x00,wp_drv:0x00
mode:DIO, clock div:1
load:0x3fff0030,len:1344
load:0x40078000,len:13964
load:0x40080400,len:3600
entry 0x400805f0
[   451][I][esp32-hal-psram.c:96] psramInit(): PSRAM enabled
NET: Connecting to WiFi ....
NET: Connected to AP successfully!
NET: IP=10.11.12.13, RSSI=-72
EPD-Test_2c13b83
UTIL: ESP32 Partition table:

| Type | Sub |  Offset  |   Size   |       Label      |
| ---- | --- | -------- | -------- | ---------------- |
|  01  | 02  | 0x009000 | 0x005000 | nvs              |
|  01  | 00  | 0x00E000 | 0x002000 | otadata          |
|  00  | 10  | 0x010000 | 0x140000 | app0             |
|  00  | 11  | 0x150000 | 0x140000 | app1             |
|  01  | 82  | 0x290000 | 0x160000 | spiffs           |
|  01  | 03  | 0x3F0000 | 0x010000 | coredump         |
| ---- | --- | -------- | -------- | ---------------- |

[  2236][I][util.cpp:186] partitionTable(): max APP size: 1280 kB
[  2238][I][util.cpp:202] psRAM(): ========================================
[  2245][W][util.cpp:217] psRAM(): PSRAM is not enabled on this board
[  2251][I][util.cpp:219] psRAM(): ========================================
[  2257][I][util.cpp:220] psRAM(): Internal RAM  size   : 321880
[  2263][I][util.cpp:221] psRAM(): Internal RAM  free   : 251136
[  2269][I][util.cpp:222] psRAM(): ========================================
[  2276][I][util.cpp:258] initID(): ESP32: chip=1, cores=2, revision=3, radio=WiFi/BT/BLE flash=4MB external

```

lewisxhe, 2023-12-15:
It seems that the PSRAM has failed. Contact the seller to replace it.

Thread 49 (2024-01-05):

Sleep current on T5 2.13" v2.3.1

ldab, 2024-01-05:
Related to https://github.com/Xinyuan-LilyGO/LilyGo-T5-Epaper-Series/issues/29

When using the example [examples/GxEPD_Example/GxEPD_Example.ino](https://github.com/Xinyuan-LilyGO/LilyGo-T5-Epaper-Series/blob/master/examples/GxEPD_Example/GxEPD_Example.ino) the sleep current is 635uA from when measuring from the VBAT pin.

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

How was the 300uA measured?

lewisxhe, 2024-04-10:
Measured on the onboard CP2104 UART
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

claudobahn, 2024-11-14:
@lewisxhe I'm having the same issue as @ldab with the same board (T5 2.13" v2.3.1 w/ DEPG0213BN), the lowest I've been able to achieve w/ sleep current is around 600-700 micro amps.

Is your test running with an unmodified board? What sketch are you using? And are you isolating or resetting any of the GPIO before going to deep sleep? Changing any pull-up/down settings?

I'm wondering if there's current drain because of a pull-up/down resistor, either internal to the ESP32 or on the T5 board.

lewisxhe, 2024-11-15:
I did not make any changes, and the example was also tested using https://github.com/Xinyuan-LilyGO/LilyGo-T5-Epaper-Series/blob/master/examples/GxEPD_Example/GxEPD_Example.ino. The only difference is the current test tool.

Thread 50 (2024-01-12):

incorrect pinout on the pinout sheet

rdekens, 2024-01-12:
couldn't get the 266 EPD to work with the examples  until I went back to  GxEPD rather than GxEPD2.
Traced it back to GxEPD using the boards.h file - and from there to the correct pinouts to the 2.66 " epd -
motably - as per the schematics - which are correct  - the Display is
MOSI  23   : correct
MISO  17 :
CLK 18 : correct
CS 5 : correct
RST :  16  WRONG ->  **4**
BUSY 4  WRONG -> **34**
DC not shown - > 19 -  - PIn 19 should be shown as used by the display and not available without due care

pin 17 Appears to have been unused - would have been good if it had been routed out instead of 19 , or used instead with the display.
see attatched modified diagram
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

the examples need to be adjusted to account for the different pinout also

lewisxhe, 2024-01-16:
Thanks for the feedback, I have given it and will make changes soon

Closed 2024-01-16.

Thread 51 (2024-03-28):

Access I2C on T-Dispay E-paper 1.02"

dominator15, 2024-03-28:
Hi, on the model T-Dispay E-paper 1.02" i do not see any output for i2c such as on TTGO T-Display 1.14 Inch LCD. On LCD version there is pin 21 and 22 for I2C but on e-paper version pinout i do not see any port labelled i2c. Does this board not support I2C?

lewisxhe, 2024-04-10:
I2C is freely mapped to IO on both sides, and SDA and SCL are specified during initialization.
For example
```
Wire.begin(5//sda,6//scl)
```

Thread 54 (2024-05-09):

support of T5 Screen-4.7-S3

mars3142, 2024-05-09:
Device: https://www.lilygo.cc/products/t5-4-7-inch-e-paper-v2-3

Are there any plans to support this board?

asg02fever, 2024-07-01:
hey man  , i got the same board , i had only the factory firmware , and i tried to install new one since then there is no working firmware to turn on the display now i havea useless board , can you tell me if u managed to make it work ?

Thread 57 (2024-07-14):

Battery charging stops

mjdudak, 2024-07-14:
I have a T5s 2.7inch. I have hooked up a 3.7V LiPo battery to it and the bright blue charging light will come on for a few seconds but then both the charging light and the regular blinking light from the board running stop, even though it is still plugged into USB power. When measuring the battery with a multimeter, it only reads about 2.1V, which is the same as the reading I am getting from GPIO35. Even when connected for several hours, the battery charge does not go above 2.1V.

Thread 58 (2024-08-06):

PCB Footprints and 3D files (PCB layout) for c2.3.1/v2.3.2

CraigHutchinson, 2024-08-06:
As per title, would be good to have 3D STL of the PCB or layout file as to to be able design a case

Chr0my1702, 2024-08-31:
did this get anywhere?

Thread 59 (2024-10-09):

T5 2.13 VBAT Pin

syoung22071958, 2024-10-09:
Does anyone have information about this pin ?
Is this pin for power supply to the board ?
And if it is, what is the voltage range ?
I don't understand why it is so hard to find this out.
Thanks.

lewisxhe, 2024-10-09:
GPIO35

darkroom2, 2024-10-09:
VBAT pin is connected direct to a battery + terminal

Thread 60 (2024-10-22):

Better build instructions please

drder66, 2024-10-22:
What is the build environment? Is it Visual Studio or something else?
On linux, that would appear to need the Arduino IDE Extension. But where to copy the libraries to?
Can't get past include path problems - added an include to reach boards.h, but most of the other include files are somewhere else.

drder66, 2024-10-22:
So I figured it's the Arduino IDE (standalone, nothing to do with Visual Studio). That sorted, the instructions work

Closed 2024-10-22.

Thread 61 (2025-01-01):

T5 2.13 burned out?

HenryData, 2025-01-01:
Hi, I was trying to upload the sketch from https://github.com/jasonful/Tides/tree/master when at some point the screen greyed out and the T5 stopped communicating.
I've been trying to flash the binary file back to it but it just goes to sync for awhile before I click stop and it outputs
no log file output ...
I have an adafruit TPL5110 board connected connected to pin 13, gnd, and Vbat. And a LI battery connected to the ground and VDD pins on the TPL5110. The TPL5110 still lights up when I plug in the USB to the board or connect the battery to the TPL5110.
I cant reset the screen or upload any code. I guess I must have burnt out the hardware but I'm not sure how.
Is it possible that having the USB and the battery connected at the same time damaged something?
Thanks
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

lewisxhe, 2025-01-02:
Connecting the battery and USB at the same time will not damage the board.

Are you unable to upload now?

Find IO0, connect it to GND, then power on, and finally write the firmware to try

HenryData, 2025-01-03:
After cleaning off a corner of flux and doing this it seems to be unstuck. Still having trouble uploading the sketch but thats a seperate issue and at least the screens responding. Thanks!

Closed 2025-01-03.

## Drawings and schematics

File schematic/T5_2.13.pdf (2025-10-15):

# USB

UART | LDO

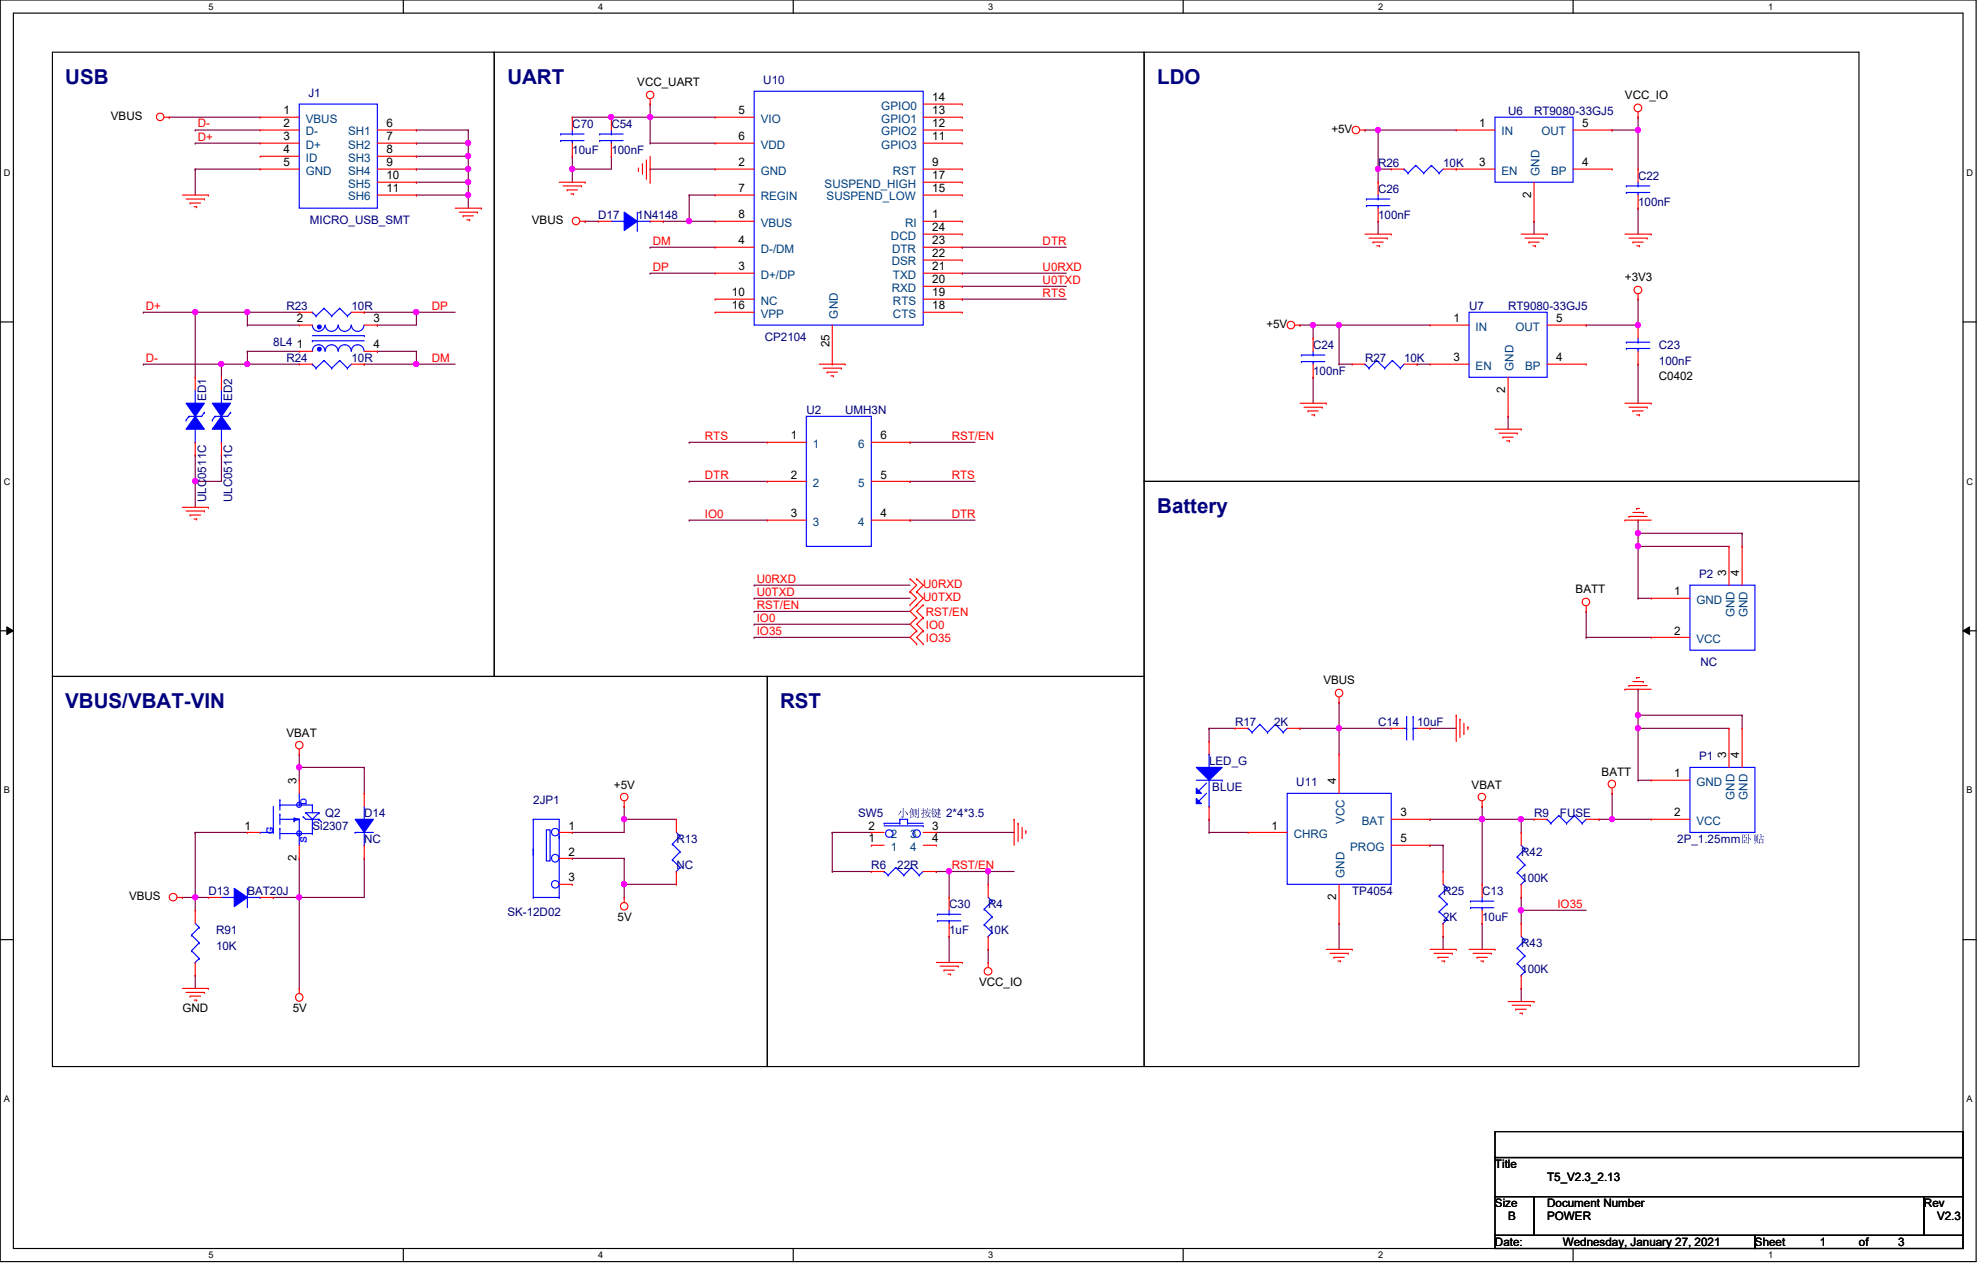
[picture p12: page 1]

# 2.13_Ink screen

## CS-D/IO5

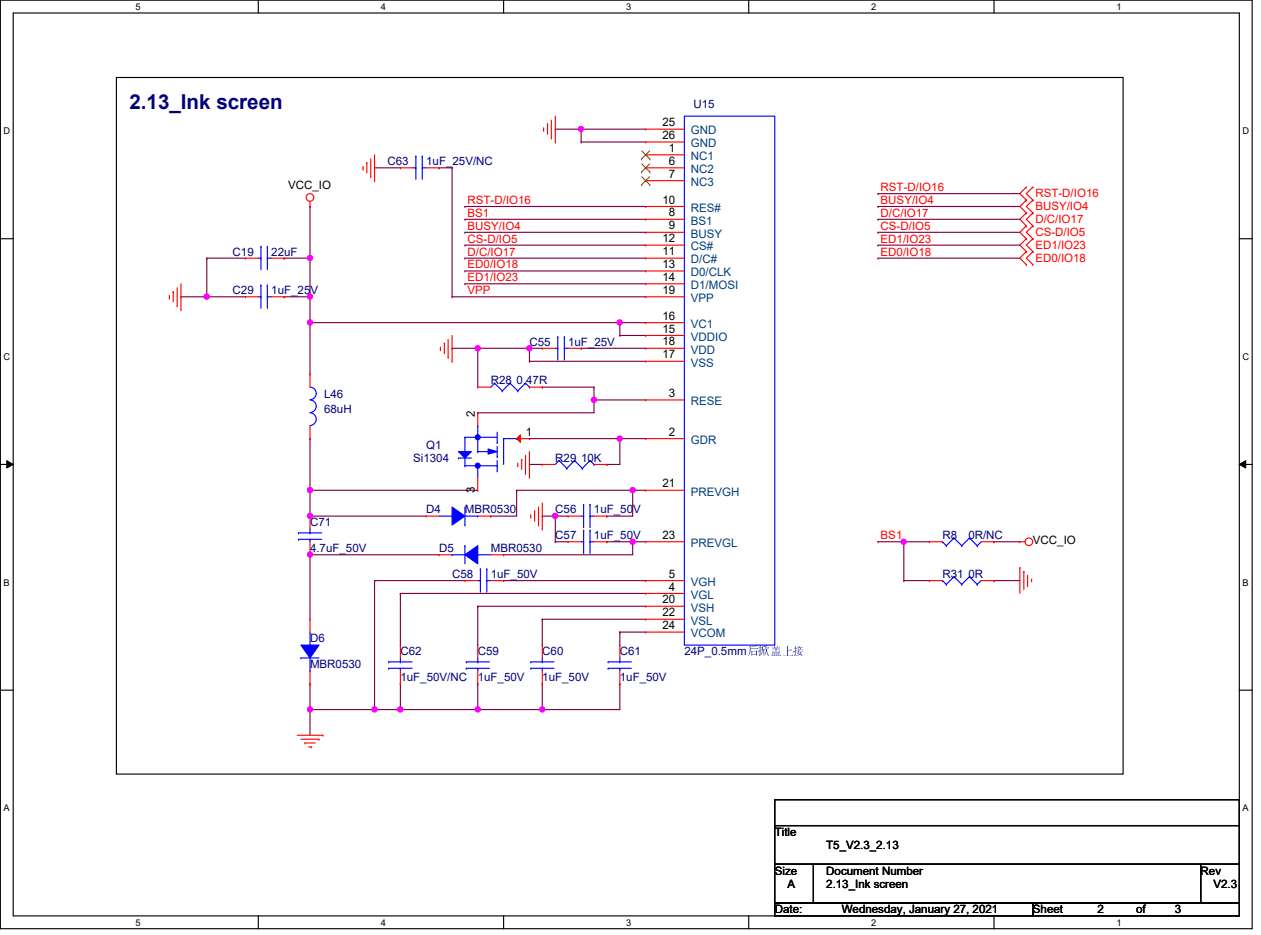
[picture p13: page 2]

Core | GPIO

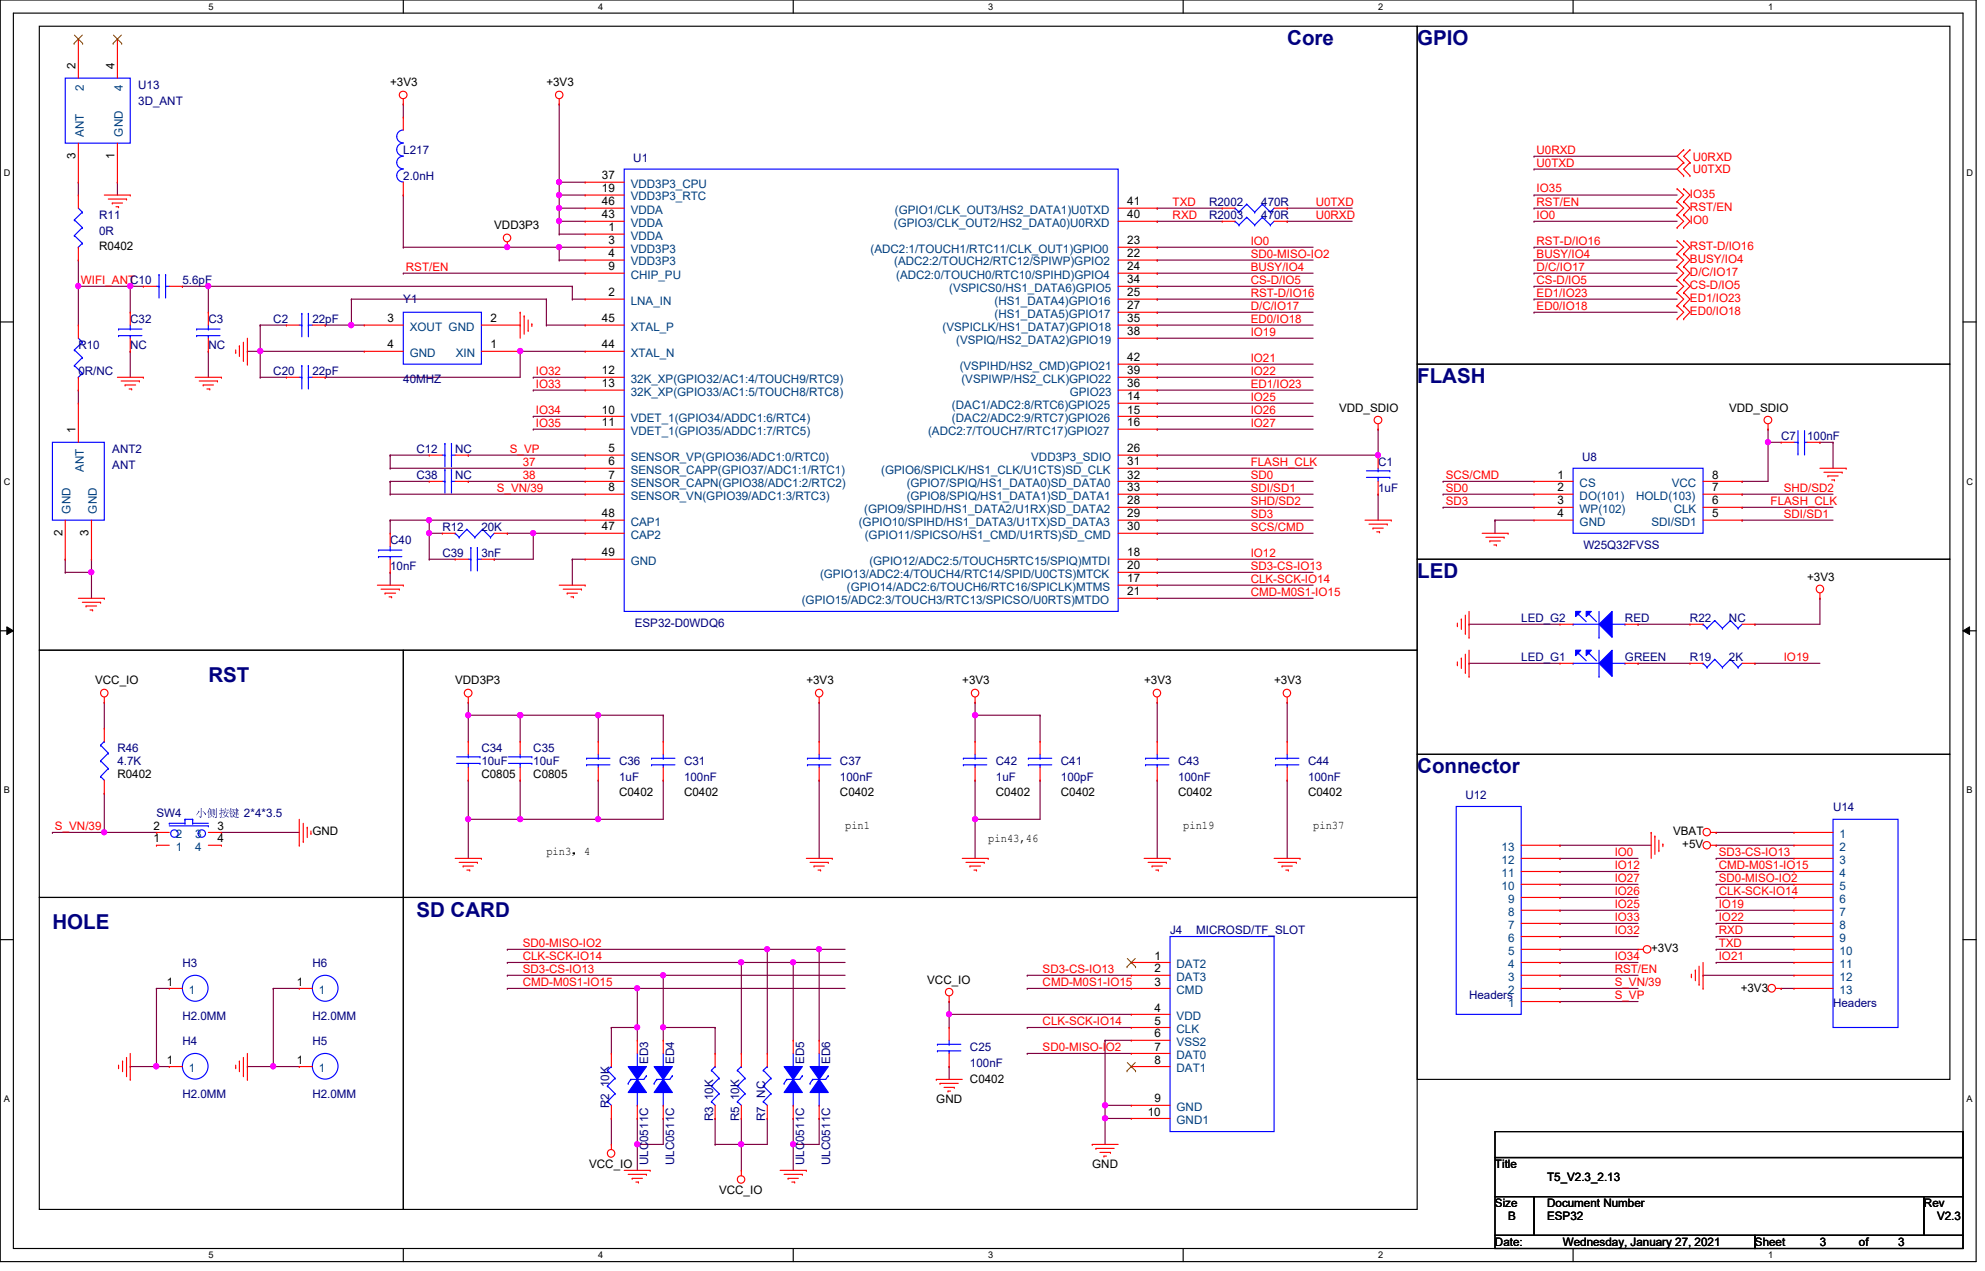
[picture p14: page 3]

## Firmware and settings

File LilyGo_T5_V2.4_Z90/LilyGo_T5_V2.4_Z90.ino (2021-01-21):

#include <SD.h>
#include <SPI.h>
#include <Button2.h>
#include <GxEPD2_3C.h>          //GxEPD2  https://github.com/ZinggJM/GxEPD2
#include <Fonts/FreeMonoBold9pt7b.h>
#include <Fonts/FreeMonoBold12pt7b.h>
#include <Fonts/FreeMonoBold18pt7b.h>
#include <Fonts/FreeMonoBold24pt7b.h>


#define ELINK_BUSY 4
#define ELINK_RESET 16
#define ELINK_DC 17
#define ELINK_SS 5

#define SPI_MOSI 23
#define SPI_MISO -1 //elink no use
#define SPI_CLK 18

#define SDCARD_SS 13
#define SDCARD_MOSI 15
#define SDCARD_MISO 2
#define SDCARD_CLK 14

#define BUTTON_1 37
#define BUTTON_2 38
#define BUTTON_3 39

#define SPEAKER_OUT 25
#define AMP_POWER_CTRL 19
#define CHANNEL_0 0
#define BUTTONS_MAP \
    {               \
        37, 38, 39  \
    }

GxEPD2_3C<GxEPD2_154_Z90c, GxEPD2_154_Z90c::HEIGHT> display(GxEPD2_154_Z90c(
            /*CS*/ ELINK_SS, /*DC*/ ELINK_DC, /*RST*/ ELINK_RESET, /*BUSY*/ ELINK_BUSY)); // GDEH0154Z90


//width:150,height:39
int bmpWidth = 150, bmpHeight = 39;
const unsigned char lilygo[] = {0x00, 0x00, 0x00, 0x00, 0x00, 0x00, 0x00, 0x00, 0x00, 0x00, 0x00, 0x00, 0x00, 0x00, 0x00, 0x00, 0x00, 0x00, 0x00, 0x00, 0x00, 0x00, 0x00, 0x00, 0x00, 0x00, 0x00, 0x00, 0x00, 0x00, 0x00, 0x00, 0x00, 0x00, 0x00, 0x00, 0x00, 0x00, 0x00, 0x00, 0x00, 0x00, 0x00, 0x00, 0x00, 0x00, 0x00, 0x00, 0x00, 0x00, 0x00, 0x00, 0x00, 0x00, 0x00, 0x00, 0x00, 0x00, 0x00, 0x00, 0x00, 0x00, 0x00, 0x00, 0x00, 0x00, 0x00, 0x00, 0x00, 0x00, 0x00, 0x00, 0x00, 0x01, 0xf7, 0x00, 0x00, 0x00, 0x00, 0x00, 0x00, 0x00, 0x00, 0x00, 0x00, 0x00, 0x00, 0x00, 0x00, 0x00, 0x00, 0x00, 0x07, 0x31, 0x80, 0x00, 0x00, 0x00, 0x00, 0x00, 0x00, 0x00, 0x00, 0x00, 0x00, 0x00, 0x00, 0x00, 0x00, 0x00, 0x00, 0x0f, 0xfc, 0xc0, 0x00, 0x00, 0x00, 0x00, 0x00, 0x00, 0x00, 0x00, 0x00, 0x00, 0x00, 0x00, 0x00, 0x00, 0x00, 0x00, 0x0d, 0xfe, 0x60, 0x00, 0x00, 0x00, 0x00, 0x00, 0x00, 0x00, 0x00, 0x00, 0x00, 0x00, 0x00, 0x00, 0x00, 0x00, 0x00, 0x19, 0xff, 0x20, 0x7f, 0xc0, 0x03, 0xfc, 0x7f, 0x80, 0x07, 0xf8, 0x0f, 0xf0, 0x00, 0xfe, 0x00, 0x03, 0xff, 0x80, 0x19, 0xe7, 0x30, 0x7f, 0xc0, 0x03, 0xfc, 0x7f, 0x80, 0x07, 0xfc, 0x0f, 0xf0, 0x07, 0xff, 0xc0, 0x0f, 0xff, 0xe0, 0x19, 0xe7, 0xb0, 0x7f, 0xc0, 0x03, 0xfc, 0x7f, 0x80, 0x03, 0xfc, 0x1f, 0xe0, 0x0f, 0xff, 0xe0, 0x1f, 0xff, 0xf8, 0x19, 0xff, 0x10, 0x7f, 0xc0, 0x03, 0xfc, 0x7f, 0x80, 0x03, 0xfe, 0x1f, 0xe0, 0x1f, 0xff, 0xf0, 0x3f, 0xff, 0xfc, 0x19, 0xff, 0x10, 0x3f, 0xc0, 0x03, 0xfc, 0x7f, 0x80, 0x03, 0xfe, 0x1f, 0xc0, 0x3f, 0xff, 0xf0, 0x7f, 0xff, 0xfe, 0x19, 0xfe, 0x10, 0x3f, 0xc0, 0x03, 0xfc, 0x7f, 0x80, 0x01, 0xfe, 0x3f, 0xc0, 0x7f, 0xff, 0xe0, 0x7f, 0xff, 0xfe, 0x19, 0xfe, 0x10, 0x3f, 0xc0, 0x03, 0xfc, 0x7f, 0x80, 0x01, 0xff, 0x3f, 0x80, 0xff, 0xc7, 0xc0, 0xff, 0xff, 0xff, 0x1d, 0xfe, 0x10, 0x3f, 0xc0, 0x03, 0xfc, 0x7f, 0x80, 0x00, 0xff, 0x7f, 0x80, 0xff, 0x81, 0x80, 0xff, 0xef, 0xff, 0x1d, 0xef, 0x00, 0x3f, 0xc0, 0x03, 0xfc, 0x7f, 0x80, 0x00, 0xff, 0xff, 0x00, 0xff, 0x00, 0x00, 0xff, 0xc3, 0xff, 0x8f, 0xef, 0x00, 0x3f, 0xc0, 0x03, 0xfc, 0x7f, 0x80, 0x00, 0x7f, 0xff, 0x01, 0xff, 0x00, 0x01, 0xff, 0xc3, 0xff, 0x8f, 0x87, 0x80, 0x3f, 0xc0, 0x03, 0xfc, 0x7f, 0x80, 0x00, 0x7f, 0xfe, 0x01, 0xfe, 0x00, 0x01, 0xff, 0xc1, 0xff, 0x87, 0x81, 0xc0, 0x3f, 0xc0, 0x03, 0xfc, 0x7f, 0x80, 0x00, 0x7f, 0xfe, 0x01, 0xfe, 0x1f, 0x81, 0xff, 0x81, 0xff, 0x83, 0xff, 0x80, 0x3f, 0xc0, 0x03, 0xfc, 0x7f, 0x80, 0x00, 0x3f, 0xfc, 0x01, 0xfe, 0x3f, 0xf9, 0xff, 0x81, 0xff, 0x80, 0xfe, 0x00, 0x3f, 0xc0, 0x03, 0xfc, 0x7f, 0x80, 0x00, 0x3f, 0xfc, 0x01, 0xfe, 0x3f, 0xf9, 0xff, 0x81, 0xff, 0x80, 0x00, 0x00, 0x3f, 0xc0, 0x03, 0xfc, 0x7f, 0x80, 0x00, 0x1f, 0xf8, 0x01, 0xfe, 0x3f, 0xf9, 0xff, 0x81, 0xff, 0x80, 0x00, 0x00, 0x3f, 0xc0, 0x03, 0xfc, 0x7f, 0x80, 0x00, 0x1f, 0xf0, 0x01, 0xff, 0x3f, 0xf9, 0xff, 0xc1, 0xff, 0x80, 0x00, 0x00, 0x3f, 0xc0, 0x03, 0xfc, 0x7f, 0x80, 0x00, 0x0f, 0xf0, 0x01, 0xff, 0x3f, 0xf8, 0xff, 0xc1, 0xff, 0x80, 0x00, 0x00, 0x3f, 0xc0, 0x03, 0xfc, 0x7f, 0x80, 0x00, 0x0f, 0xf0, 0x00, 0xff, 0x9f, 0xf8, 0xff, 0xc1, 0xff, 0x80, 0x00, 0x00, 0x3f, 0xc0, 0x03, 0xfc, 0x7f, 0x80, 0x00, 0x0f, 0xf0, 0x00, 0xff, 0x83, 0xf0, 0xff, 0xe1, 0xff, 0x00, 0x00, 0x00, 0x3f, 0xfc, 0x03, 0xfc, 0x7f, 0xf8, 0x00, 0x0f, 0xf0, 0x00, 0xff, 0xe3, 0xf0, 0x7f, 0xff, 0xff, 0x00, 0x00, 0x00, 0x3f, 0xff, 0xe3, 0xfc, 0x7f, 0xff, 0xc0, 0x0f, 0xf0, 0x00, 0x7f, 0xff, 0xf0, 0x7f, 0xff, 0xfe, 0x00, 0x00, 0x00, 0x3f, 0xff, 0xe3, 0xfc, 0x7f, 0xff, 0xc0, 0x0f, 0xf0, 0x00, 0x7f, 0xff, 0xf0, 0x3f, 0xff, 0xfe, 0x00, 0x00, 0x00, 0x3f, 0xff, 0xe3, 0xfc, 0x7f, 0xff, 0xc0, 0x0f, 0xf0, 0x00, 0x3f, 0xff, 0xf0, 0x3f, 0xff, 0xfc, 0x00, 0x00, 0x00, 0x3f, 0xff, 0xe3, 0xfc, 0x7f, 0xff, 0xc0, 0x0f, 0xf0, 0x00, 0x1f, 0xff, 0xf0, 0x1f, 0xff, 0xfc, 0x00, 0x00, 0x00, 0x3f, 0xff, 0xe3, 0xf8, 0x7f, 0xff, 0xc0, 0x0f, 0xf0, 0x00, 0x0f, 0xff, 0xf0, 0x0f, 0xff, 0xf8, 0x00, 0x00, 0x00, 0x1f, 0xff, 0xc3, 0xf8, 0x1f, 0xff, 0xc0, 0x0f, 0xe0, 0x00, 0x03, 0xff, 0xe0, 0x03, 0xff, 0xe0, 0x00, 0x00, 0x00, 0x00, 0x3f, 0xc0, 0xf0, 0x00, 0x3f, 0x80, 0x07, 0xe0, 0x00, 0x00, 0xff, 0x80, 0x01, 0xff, 0xc0, 0x00, 0x00, 0x00, 0x00, 0x00, 0x00, 0x00, 0x00, 0x00, 0x00, 0x00, 0x00, 0x00, 0x00, 0x00, 0x00, 0x00, 0x3e, 0x00, 0x00, 0x00, 0x00, 0x00, 0x00, 0x00, 0x00, 0x00, 0x00, 0x00, 0x00, 0x00, 0x00, 0x00, 0x00, 0x00, 0x00, 0x00, 0x00, 0x00, 0x00, 0x00, 0x00, 0x00, 0x00, 0x00, 0x00, 0x00, 0x00, 0x00, 0x00, 0x00, 0x00, 0x00, 0x00, 0x00, 0x00, 0x00, 0x00, 0x00, 0x00, 0x00, 0x00, 0x00, 0x00, 0x00, 0x00, 0x00, 0x00, 0x00, 0x00, 0x00, 0x00, 0x00, 0x00, 0x00, 0x00, 0x00, 0x00, 0x00};

const char *skuNum = "SKU:H215";
int startX = 30, startY = 50;

Button2 *pBtns = nullptr;
SPIClass SDSPI(VSPI);
uint8_t g_btns[] = BUTTONS_MAP;
bool sdOK = false;


void button_callback(Button2 &b)
{
    for (int i = 0; i < sizeof(g_btns) / sizeof(g_btns[0]); ++i) {
        if (pBtns[i] == b) {
            Serial.printf("Button: %u Press\n", pBtns[i].getAttachPin());
            ledcWriteTone(CHANNEL_0, 1000);
            delay(200);
            ledcWriteTone(CHANNEL_0, 0);
        }
    }
}

void button_init()
{
    uint8_t args = sizeof(g_btns) / sizeof(g_btns[0]);
    pBtns = new Button2[args];
    for (int i = 0; i < args; ++i) {
        pBtns[i] = Button2(g_btns[i]);
        pBtns[i].setPressedHandler(button_callback);
    }
}


void setup()
{
    Serial.begin(115200);

    Serial.println();

    Serial.println("setup");

    SPI.begin(SPI_CLK, SPI_MISO, SPI_MOSI);

    display.init(); // enable diagnostic output on Serial

    //Serial.println("helloWorld");
    display.setRotation(1);
    display.setFont(&FreeMonoBold9pt7b);
    display.setTextColor(GxEPD_BLACK);
    int16_t tbx, tby; uint16_t tbw, tbh;
    display.getTextBounds("HelloWorld", 0, 0, &tbx, &tby, &tbw, &tbh);
    // center bounding box by transposition of origin:
    uint16_t x = ((display.width() - tbw) / 2) - tbx;
    uint16_t y = ((display.height() - tbh) / 2) - tby;
    display.setFullWindow();
    display.firstPage();
    do {
        display.fillScreen(GxEPD_WHITE);
        display.setCursor(x, y);
        display.print("HelloWorld");
    } while (display.nextPage());
    //Serial.println("helloWorld done");


    pinMode(AMP_POWER_CTRL, OUTPUT);
    digitalWrite(AMP_POWER_CTRL, HIGH);

    ledcSetup(CHANNEL_0, 1000, 8);
    ledcAttachPin(SPEAKER_OUT, CHANNEL_0);
    int i = 3;
    while (i--) {
        ledcWriteTone(CHANNEL_0, 1000);
        delay(200);
        ledcWriteTone(CHANNEL_0, 0);
    }

    button_init();

    display.setRotation(1);
    display.fillScreen(GxEPD_WHITE);
    display.setTextColor(GxEPD_BLACK);
    display.setFont(&FreeMonoBold9pt7b);
    display.setCursor(0, 0);

    SDSPI.begin(SDCARD_CLK, SDCARD_MISO, SDCARD_MOSI, SDCARD_SS);

    if (!SD.begin(SDCARD_SS, SDSPI)) {
        sdOK = false;
    } else {
        sdOK = true;
    }

    display.setFullWindow();
    display.firstPage();
    do {
        display.fillScreen(GxEPD_WHITE);
        display.drawBitmap(startX, startY,  lilygo, bmpWidth, bmpHeight, GxEPD_RED);
        display.setCursor(display.width()   / 2 - 40, display.height() - 10);
#if defined(HAS_RED_COLOR)
        display.setTextColor(GxEPD_RED);
#endif
        display.setCursor(display.width()  - display.width() / 2, display.height() - 35);
        display.println(skuNum);
        display.setTextColor(GxEPD_BLACK);
        if (sdOK) {
            uint32_t cardSize = SD.cardSize() / (1024 * 1024);
            display.println("SDCard:" + String(cardSize) + "MB");
        } else {
            display.println("SDCard  None");
        }
    } while (display.nextPage());

}


void loop()
{
    for (int i = 0; i < sizeof(g_btns) / sizeof(g_btns[0]); ++i) {
        pBtns[i].loop();
    }
}

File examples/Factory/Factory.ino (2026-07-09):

/**
 * @file      Factory.ino
 * @author    Lewis He (lewishe@outlook.com)
 * @license   MIT
 * @copyright Copyright (c) 2026  ShenZhen XinYuan Electronic Technology Co., Ltd
 * @date      2026-07-09
 *
 */
#define EPD_PWR_EN              (12)    // Only V2.4 Version , v2.3.1 version not have this pin
#define BUTTON_1                (39)
#define ADC_PIN                 (35)

#include <SD.h>
#include <FS.h>
#include <U8g2_for_Adafruit_GFX.h>
#include <WiFi.h>
#include <GxEPD2_BW.h>
#include <GxEPD2_3C.h>
#include <GxEPD2_4C.h>

// GxEPD2 display selection (uncomment ONE and set its PANEL_NAME)

// DEPG0213BN 122x250, SSD1680, TTGO T5 2.13 V2.4 (FPC-7528B)
#define PANEL_NAME "DEPG0213BN"
GxEPD2_BW<GxEPD2_213_BN, GxEPD2_213_BN::HEIGHT> display(GxEPD2_213_BN(/*CS=5*/ 5, /*DC=*/ 17, /*RST=*/ 16, /*BUSY=*/ 4));

// GDEY0213B74 122x250, SSD1680, (FPC-A002 20.04.08)
// #define PANEL_NAME "GDEM0213B74"
// GxEPD2_BW<GxEPD2_213_B74, GxEPD2_213_B74::HEIGHT> display(GxEPD2_213_B74(/*CS=5*/ 5, /*DC=*/ 17, /*RST=*/ 16, /*BUSY=*/ 4)); // GDEM0213B74 122x250, SSD1680

U8G2_FOR_ADAFRUIT_GFX u8g2Fonts;

SPIClass SDSPI(VSPI);

int16_t g_voltageY = 0;
uint32_t interval = 0;
uint32_t loopCount = 0;

/*
 * Scan WiFi networks and return the count.
 * Results are also printed to Serial.
 */
int scanWiFi()
{
    WiFi.mode(WIFI_STA);
    WiFi.disconnect();
    delay(100);

    Serial.println("Scanning WiFi...");
    int n = WiFi.scanNetworks();

    Serial.println("Scan done");
    if (n == 0) {
        Serial.println("No networks found");
    } else {
        Serial.print(n);
        Serial.println(" networks found");
        for (int i = 0; i < n; ++i) {
            Serial.print(i + 1);
            Serial.print(": ");
            Serial.print(WiFi.SSID(i));
            Serial.print(" (");
            Serial.print(WiFi.RSSI(i));
            Serial.print(")");
            Serial.println((WiFi.encryptionType(i) == WIFI_AUTH_OPEN) ? " " : "*");
            delay(10);
        }
    }
    Serial.println("");
    WiFi.mode(WIFI_OFF);
    return n;
}

/*
 * Draw a WiFi signal icon at (x, y) with given bar count (1-3 bars).
 * bars: number of signal bars to fill (1=weak, 2=medium, 3=strong)
 */
void drawWiFiIcon(int16_t x, int16_t y, int8_t bars)
{
    /* Base arc */
    display.drawPixel(x + 4, y, GxEPD_BLACK);
    display.drawPixel(x + 3, y + 1, GxEPD_BLACK);
    display.drawPixel(x + 5, y + 1, GxEPD_BLACK);
    display.drawPixel(x + 2, y + 2, GxEPD_BLACK);
    display.drawPixel(x + 6, y + 2, GxEPD_BLACK);

    /* Bar 1 (weakest) */
    if (bars >= 1) {
        display.fillRect(x + 3, y + 4, 3, 2, GxEPD_BLACK);
    }
    /* Bar 2 (medium) */
    if (bars >= 2) {
        display.fillRect(x + 1, y + 6, 7, 2, GxEPD_BLACK);
    }
    /* Bar 3 (strong) */
    if (bars >= 3) {
        display.fillRect(x - 1, y + 8, 11, 2, GxEPD_BLACK);
    }
}

/*
 * Draw a horizontal divider line.
 */
void drawDivider(int16_t y, int16_t width)
{
    int16_t cx = display.width() / 2;
    int16_t startX = cx - width / 2;
    int16_t endX = cx + width / 2;
    display.drawLine(startX, y, endX, y, GxEPD_BLACK);
    display.drawPixel(startX - 1, y, GxEPD_BLACK);
    display.drawPixel(endX + 1, y, GxEPD_BLACK);
}

/*
 * Show a "scanning" screen so the user knows WiFi scan is in progress.
 */
void showScanningScreen()
{
    display.setRotation(0);

    uint16_t screenW = display.width();
    uint16_t screenH = display.height();

    u8g2Fonts.begin(display);
    u8g2Fonts.setFontMode(1);
    u8g2Fonts.setFontDirection(0);
    u8g2Fonts.setForegroundColor(GxEPD_BLACK);
    u8g2Fonts.setBackgroundColor(GxEPD_WHITE);

    display.setFullWindow();
    display.firstPage();
    do {
        display.fillScreen(GxEPD_WHITE);

        /* Title */
        u8g2Fonts.setFont(u8g2_font_6x12_tf);
        const char *title = "LilyGo E-Paper";
        int16_t titleW = u8g2Fonts.getUTF8Width(title);
        u8g2Fonts.setCursor((screenW - titleW) / 2, 20);
        u8g2Fonts.print(title);

        /* Panel model */
        u8g2Fonts.setFont(u8g2_font_5x7_tf);
        const char *panel = "Panel: " PANEL_NAME;
        int16_t panelW = u8g2Fonts.getUTF8Width(panel);
        u8g2Fonts.setCursor((screenW - panelW) / 2, 32);
        u8g2Fonts.print(panel);

        /* Scanning indicator - centered */
        int16_t midY = screenH / 2 + 5;

        u8g2Fonts.setFont(u8g2_font_6x12_tf);
        const char *scanText = "Scanning WiFi";
        int16_t scanW = u8g2Fonts.getUTF8Width(scanText);
        u8g2Fonts.setCursor((screenW - scanW) / 2, midY);
        u8g2Fonts.print(scanText);

        /* Animated dots */
        u8g2Fonts.setCursor((screenW - scanW) / 2 + scanW + 2, midY);
        u8g2Fonts.print("...");

        /* Bottom hint */
        u8g2Fonts.setFont(u8g2_font_5x7_tf);
        const char *hint = "Please wait";
        int16_t hintW = u8g2Fonts.getUTF8Width(hint);
        u8g2Fonts.setCursor((screenW - hintW) / 2, screenH - 10);
        u8g2Fonts.print(hint);
    } while (display.nextPage());
}

/*
 * Read battery voltage from ADC, average 16 samples for stability.
 */
uint16_t readBatteryVoltage()
{
    uint32_t sum = 0;
    for (int i = 0; i < 16; i++) {
        sum += analogReadMilliVolts(ADC_PIN);
    }
    uint16_t voltage = (sum / 16) * 2;   // voltage divider ratio = 2
    if (voltage > 4200) voltage = 4200;  // clamp to max LiPo voltage
    return voltage;
}
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

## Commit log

2021-04-07 Added LILYGO_EPD_DISPLAY board
2021-06-24 update power
2021-06-24 update power_enable
2021-06-24 update power_enable
2022-06-01 Added schematic & readme
2024-10-07 Add 2.13 Inch dxf
    [T5_V2.3_2.13.dxf]
2025-10-16 Added deep sleep test example and logging https://github.com/Xinyuan-LilyGO/LilyGo-T5-Epaper-Series/issues/63
    [DeepSleep.ino]
2025-11-20 Added 3D
    [LILYGO_T5 2.13.stp]
2026-07-09 Add t5 v2.4 pin
2026-07-09 Update the repository to the version currently for sale.
    [LILYGO_T5 2.13.stp, T5_2.13.dxf]
2026-10-28 Add schematic
